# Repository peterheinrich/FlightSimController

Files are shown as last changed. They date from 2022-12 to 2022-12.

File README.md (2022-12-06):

# Overview
This small project implements a controller board intended for use in DIY flight simulator cockpits. The goal of the project is to create a versatile
hardware component suitable for a variety of simulated instruments (from buttons, dials and lights to glass cockpits), using a common bus 
interconnect and a common programming model and environment.

# Basic Requirements
- Flexible I/O (3.3 V digital I/O, high current H-bridge for stepper motors, analog input for sliders and potentiometers).
- Raspberry Pi CM4 connectors with HDMI/USB and parallel display connectors for resolutions (320x240 to 4k)
- RP2040 microcontroller for all low-spped I/O
- RS485 bus connector with integrated power supply via D-SUB-9 connector

# Current Project State
!!! EXPERIMENTAL, DESIGN ONLY !!!

Board Schematic:
[Schematic](/assets/FlightSimController-Schematics.pdf)

Rendered board view (front):
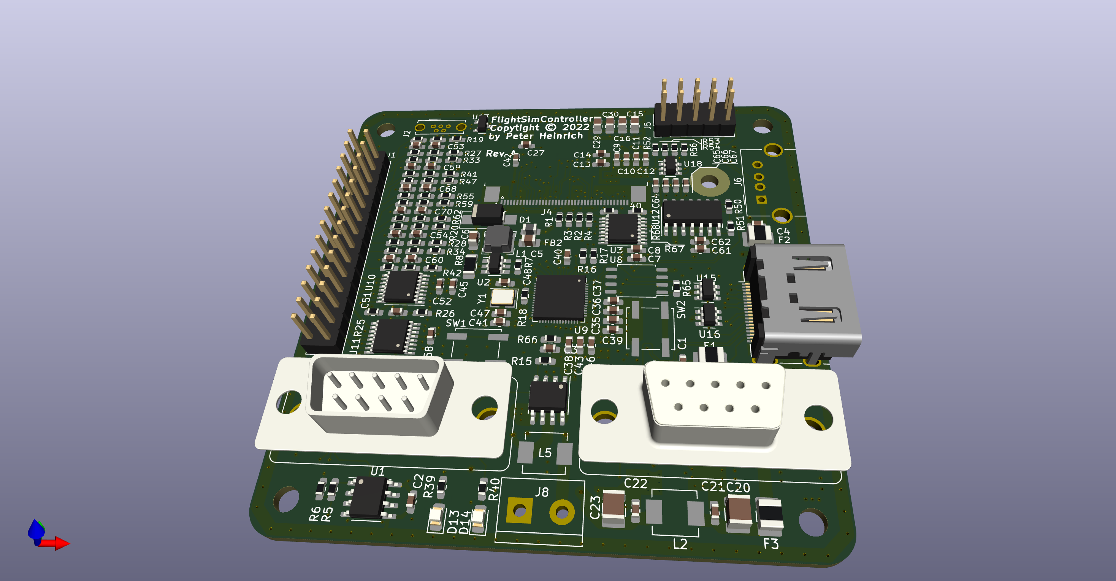
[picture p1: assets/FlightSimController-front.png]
Board-Front


Rendered board view (back):
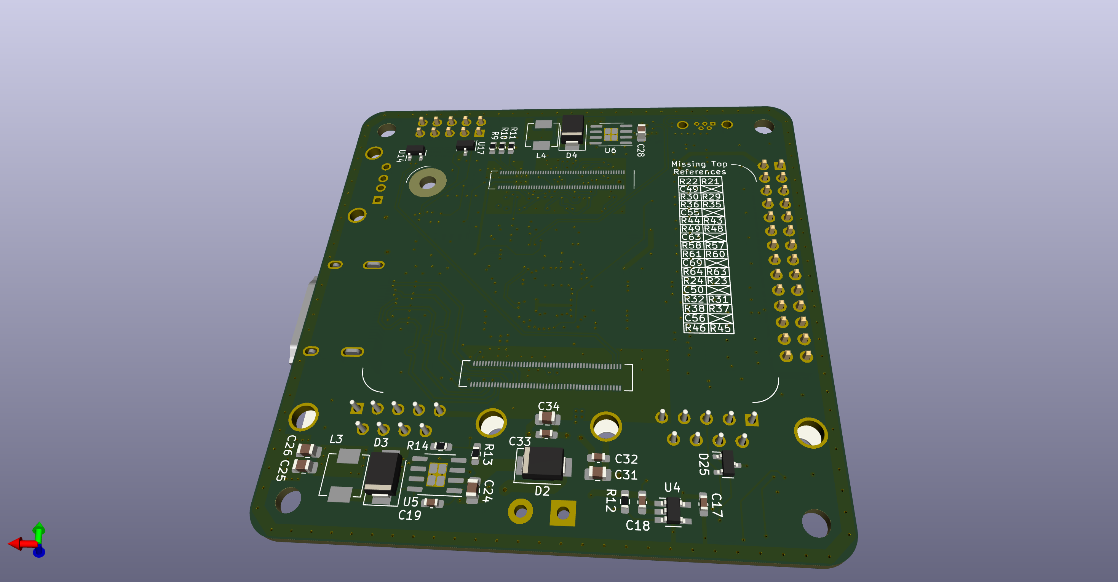
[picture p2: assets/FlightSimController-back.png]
Board-Back


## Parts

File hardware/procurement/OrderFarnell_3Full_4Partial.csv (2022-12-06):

Nr_Brd_Full | Qty_FULL | Nr_Brd_Partial | Qty_PARTIAL | QTY_TOATL | ON_FARNELL | MPN | Order_Code
3 | 35 | 4 | 27 | 213 | 1414610 | C0603C104K4RACTU | 1414610,213,C0603C104K4RACTU
3 | 6 | 4 | 3 | 30 | 9402080 | CC0603KRX5R6BB105 | 9402080,30,CC0603KRX5R6BB105
3 | 2 | 4 | 0 | 6 | 2611942 | GRM21BR61H475KE51L | 2611942,6,GRM21BR61H475KE51L
3 | 2 | 4 | 0 | 6 | 2611939 | GRM21BR61A476ME15L | 2611939,6,GRM21BR61A476ME15L
3 | 2 | 4 | 2 | 14 | 2309033 | EMK325ABJ107MM-T | 2309033,14,EMK325ABJ107MM-T
3 | 4 | 4 | 4 | 28 | 1762635 | GRM21BR61C106KE15L | 1762635,28,GRM21BR61C106KE15L
3 | 4 | 4 | 4 | 28 | 1907510 | GRM21BR61E226ME44L | 1907510,28,GRM21BR61E226ME44L
3 | 2 | 4 | 2 | 14 | 2773145 | C0603C270K5GACTU | 2773145,14,C0603C270K5GACTU
3 | 12 | 4 | 12 | 84 | 722236 | CC0603KRX7R9BB103 | 722236,84,CC0603KRX7R9BB103
3 | 1 | 4 | 0 | 3 | 9551280 | SS14-E3/61T | 9551280,3,SS14-E3/61T
3 | 3 | 4 | 3 | 21 | 1336557 | SSB44-E3/52T | 1336557,21,SSB44-E3/52T
3 | 1 | 4 | 1 | 7 | 3796308 | MP008279 | 3796308,7,MP008279
3 | 1 | 4 | 1 | 7 | 3796325 | MP008293 | 3796325,7,MP008293
3 | 1 | 4 | 1 | 7 | 2749175 | SM712-02HTG | 2749175,7,SM712-02HTG
3 | 2 | 4 | 0 | 6 | 2850019 | MCCFB1206TFF/375 | 2850019,6,MCCFB1206TFF/375
3 | 1 | 4 | 1 | 7 | 1652164 | SF-1206S300-2 | 1652164,7,SF-1206S300-2
3 | 3 | 4 | 0 | 9 | 1515661 | BLM21PG221SN1D | 1515661,9,BLM21PG221SN1D
3 | 1 | 4 | 1 | 7 | 3881938 | 68691-440HLF | 3881938,7,68691-440HLF
3 | 1 | 4 | 1 | 7 | 2470821 | 614105150721 | 2470821,7,614105150721
3 | 1 | 4 | 0 | 3 | 3465045 | 208658-1001 | 3465045,3,208658-1001
3 | 1 | 4 | 0 | 3 | 2528035 | 4-1734839-0 | 2528035,3,4-1734839-0
3 | 1 | 4 | 1 | 7 | 1248135 | 826925-5 | 1248135,7,826925-5
3 | 1 | 4 | 0 | 3 | 1450206 | 67643-0910 | 1450206,3,67643-0910
3 | 1 | 4 | 1 | 7 | 2401261 | L777TSEG09POL2RM8 | 2401261,7,L777TSEG09POL2RM8
3 | 1 | 4 | 1 | 7 | 1131855 | PM5.08/2/90 BLK | 1131855,7,PM5.08/2/90 BLK
3 | 1 | 4 | 1 | 7 | 2401266 | L77TSEH09SOL2RM8 | 2401266,7,L77TSEH09SOL2RM8
3 | 1 | 4 | 0 | 3 | 2329224 | SRN4018-330M | 2329224,3,SRN4018-330M
3 | 4 | 4 | 4 | 28 | 1698010 | IHLP2020BZER4R7M01 | 1698010,28,IHLP2020BZER4R7M01
3 | 2 | 4 | 0 | 6 | 2427678 | DF40C-100DP-0.4V(51) | 2427678,6,DF40C-100DP-0.4V(51)
3 | 9 | 4 | 2 | 35 | 9233130 | RC0603JR-070RL | 9233130,35,RC0603JR-070RL
3 | 3 | 4 | 3 | 21 | 9238549 | RC0603FR-073K3L | 9238549,21,RC0603FR-073K3L
3 | 1 | 4 | 1 | 7 | 3951237 | RC0603FR-132K2L | 3951237,7,RC0603FR-132K2L
3 | 9 | 4 | 8 | 59 | 9238603 | RC0603FR-0710KL | 9238603,59,RC0603FR-0710KL
3 | 1 | 4 | 0 | 3 | 3223654 | CR1206AF/-4R70EAS | 3223654,3,CR1206AF/-4R70EAS
3 | 1 | 4 | 1 | 7 | 3951497 | RC0603FR-071KP | 3951497,7,RC0603FR-071KP
3 | 2 | 4 | 2 | 14 | 3951609 | RC0603FR-0727R4L | 3951609,14,RC0603FR-0727R4L
3 | 2 | 4 | 2 | 14 | 9233385 | RC0603JR-071KL | 9233385,14,RC0603JR-071KL
3 | 12 | 4 | 12 | 84 | 2309107 | RC0603FR-13100KL | 2309107,84,RC0603FR-13100KL
3 | 24 | 4 | 24 | 168 | 9238425 | RC0603FR-07330RL | 9238425,168,RC0603FR-07330RL
3 | 4 | 4 | 4 | 28 | 3951355 | RC0603FR-074K7P | 3951355,28,RC0603FR-074K7P
3 | 2 | 4 | 2 | 14 | 3464290 | KSC721J LFS | 3464290,14,KSC721J LFS
3 | 1 | 4 | 1 | 7 | 2519495 | MAX485CSA+ | 2519495,7,MAX485CSA+
3 | 1 | 4 | 0 | 3 | 1824780 | TS19371CX6 RFG | 1824780,3,TS19371CX6 RFG
3 | 1 | 4 | 0 | 3 | 3008610 | TSC2007IPWR | 3008610,3,TSC2007IPWR
3 | 1 | 4 | 1 | 7 | 2849778 | LD2980ABM50TR | 2849778,7,LD2980ABM50TR
3 | 1 | 4 | 1 | 7 | 4028954 | ADP2303ARDZ-3.3-R7 | 4028954,7,ADP2303ARDZ-3.3-R7
3 | 1 | 4 | 1 | 7 | 4028955 | ADP2303ARDZ-5.0-R7 | 4028955,7,ADP2303ARDZ-5.0-R7
3 | 1 | 4 | 1 | 7 | 2807044 | VN5E160STR-E | 2807044,7,VN5E160STR-E
3 | 1 | 4 | 1 | 7 | 2901144 | IS25LP128F-JBLE | 2901144,7,IS25LP128F-JBLE
3 | 1 | 4 | 1 | 7 | 3766082 | RP2040CT | 3766082,7,RP2040CT
3 | 2 | 4 | 2 | 14 | 3869998 | TC78H611FNG(O,EL) | 3869998,14,TC78H611FNG(O,EL)
3 | 1 | 4 | 1 | 7 | 1630424 | MCP3424-E/SL | 1630424,7,MCP3424-E/SL
3 | 3 | 4 | 2 | 17 | 3116498 | TPD2E009DBZR | 3116498,17,TPD2E009DBZR
3 | 3 | 4 | 1 | 13 | 1751962 | HDMIULC6-4SC6 | 1751962,13,HDMIULC6-4SC6
3 | 1 | 4 | 1 | 7 | 2308709 | ABM8G-12.000MHZ-18-D2Y-T | 2308709,7,ABM8G-12.000MHZ-18-D2Y-T

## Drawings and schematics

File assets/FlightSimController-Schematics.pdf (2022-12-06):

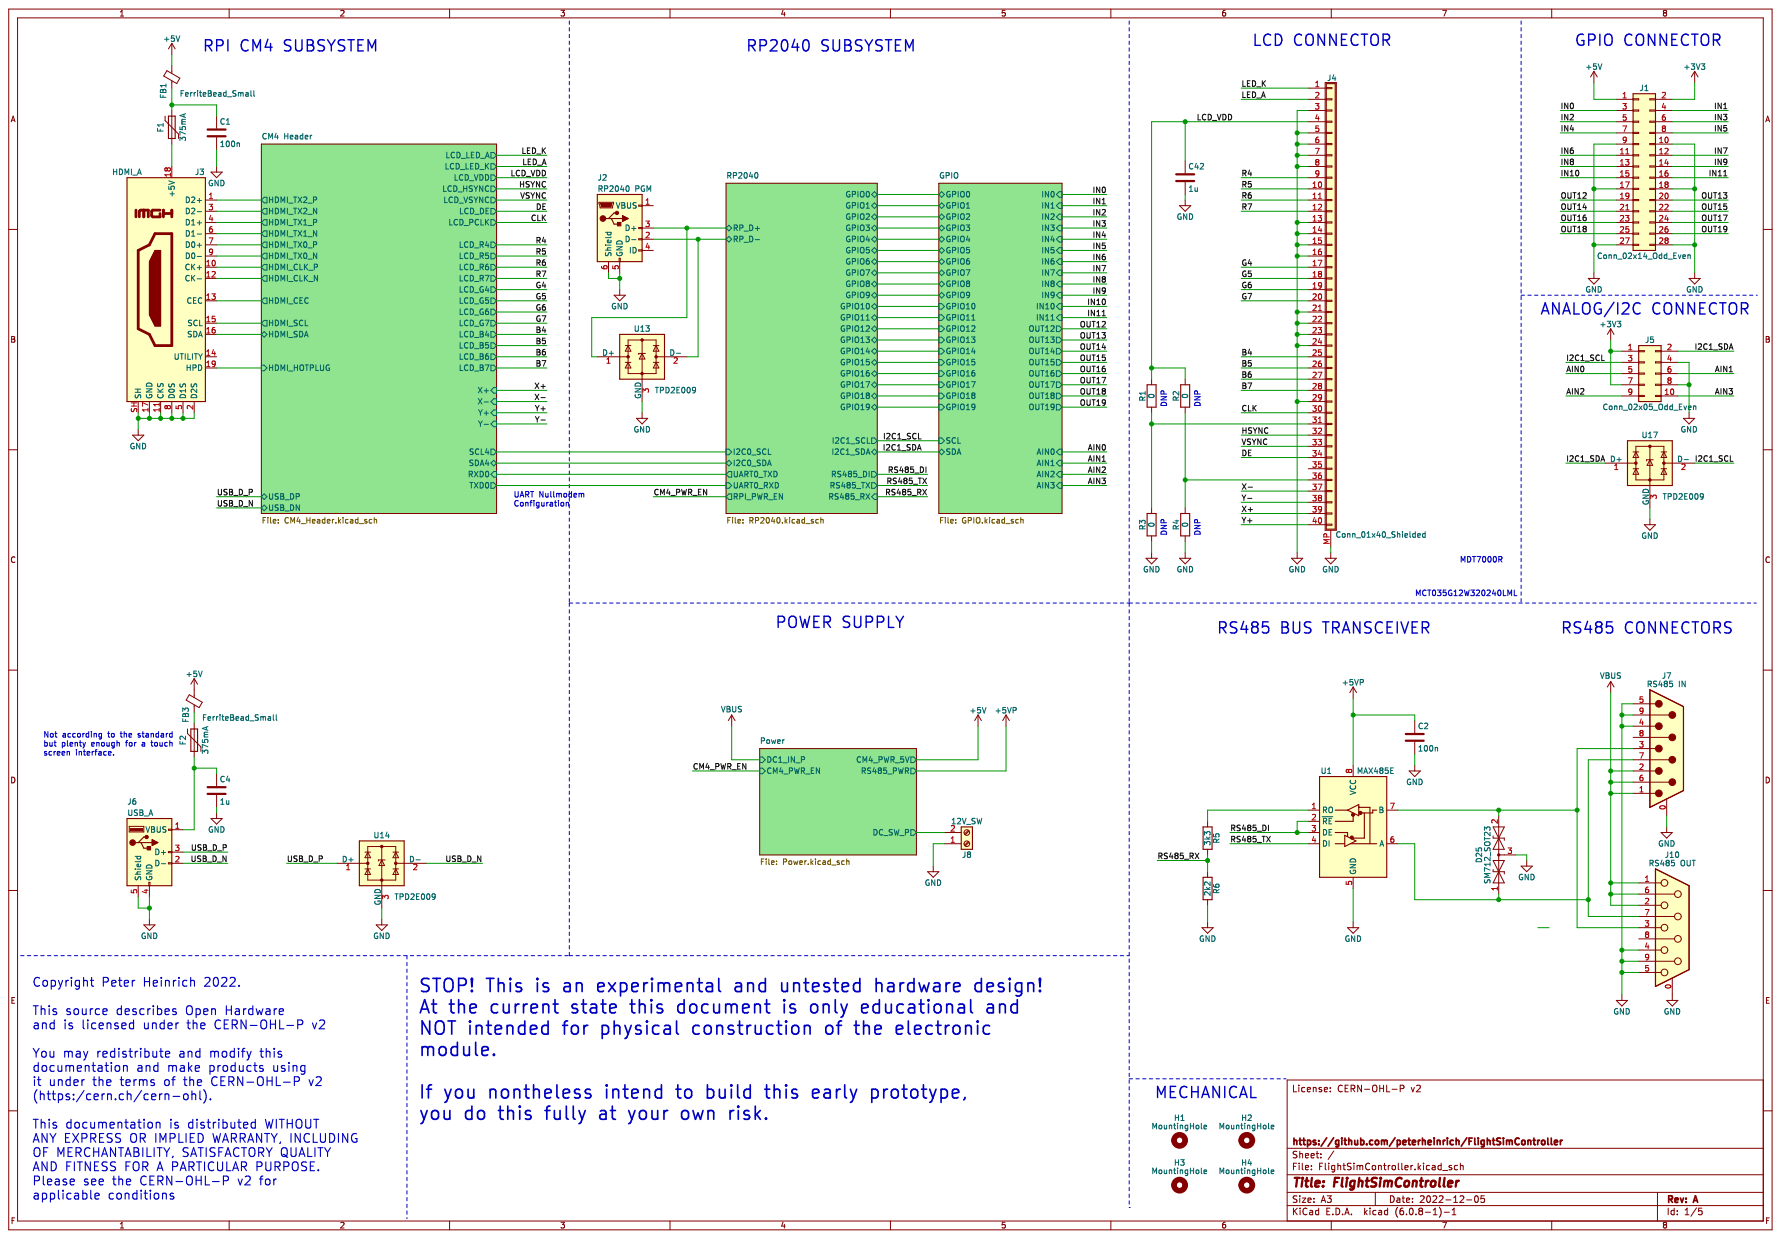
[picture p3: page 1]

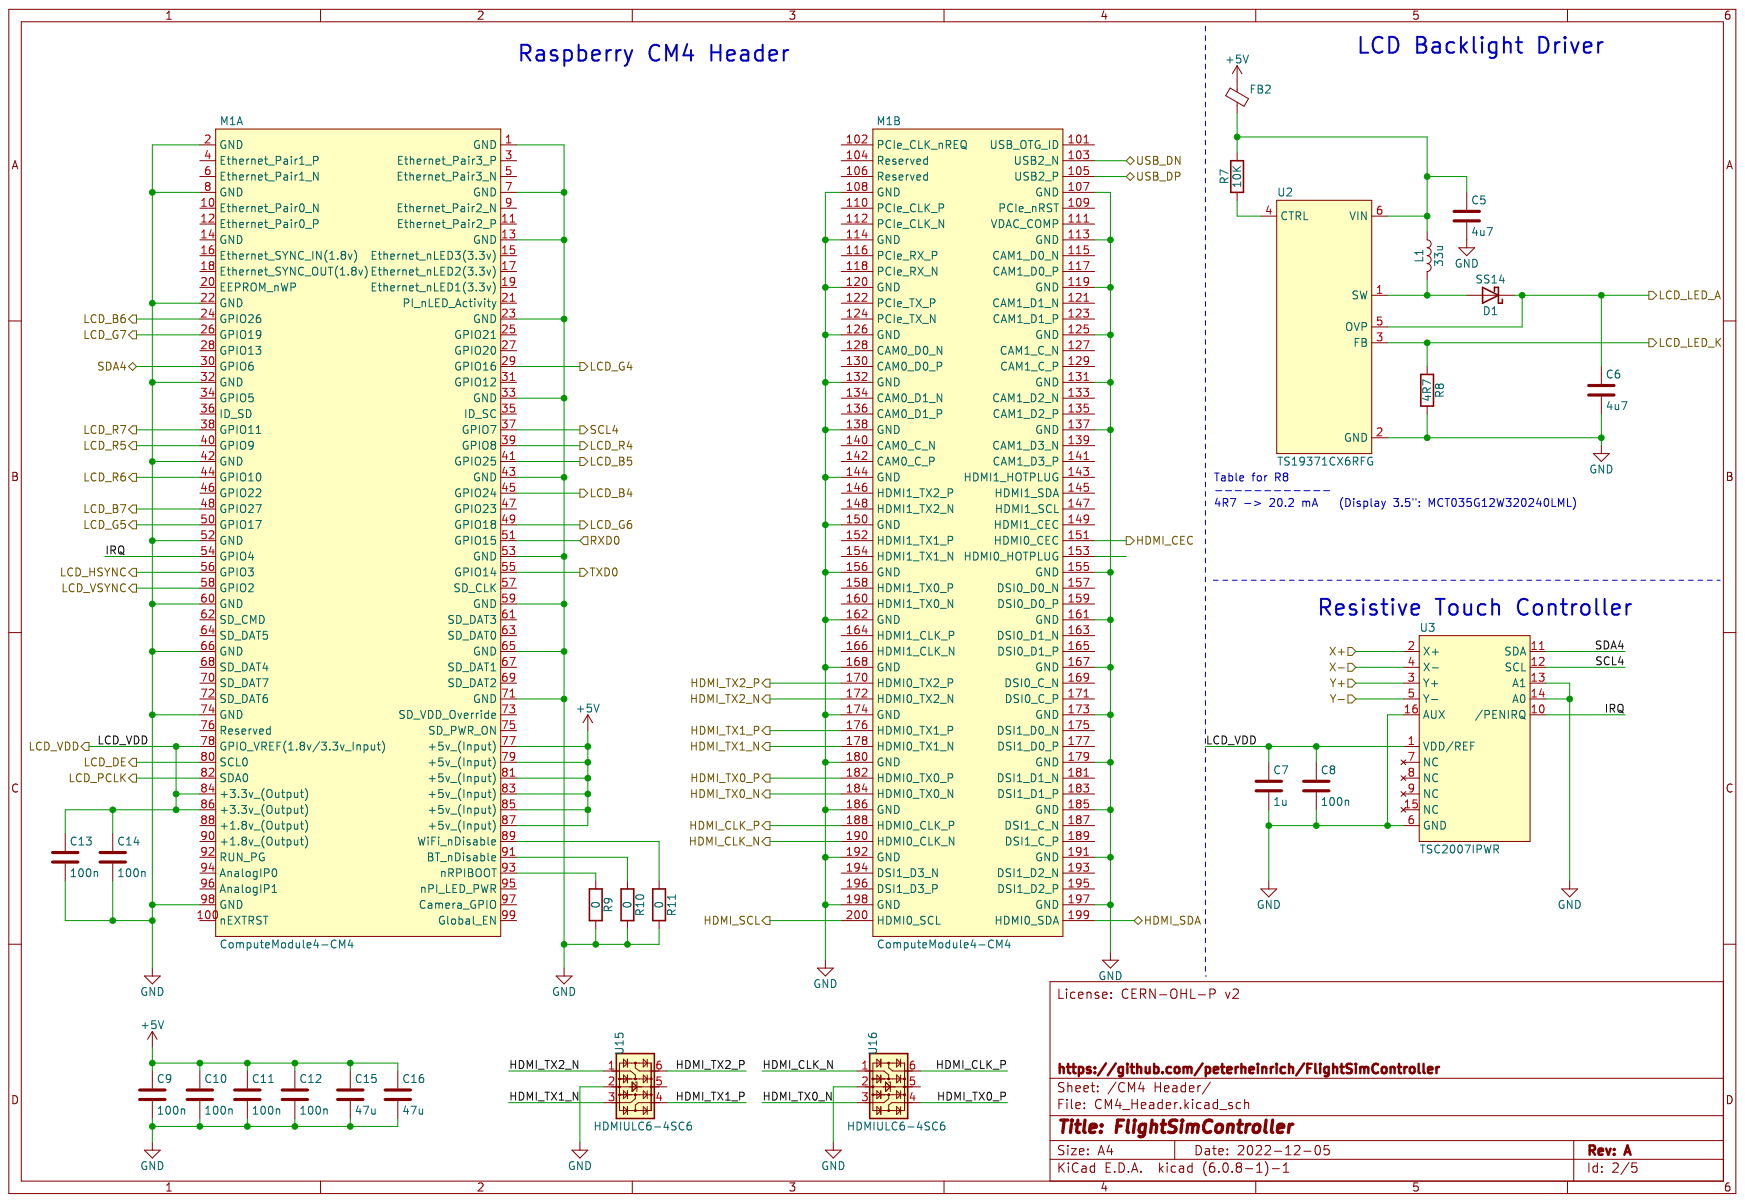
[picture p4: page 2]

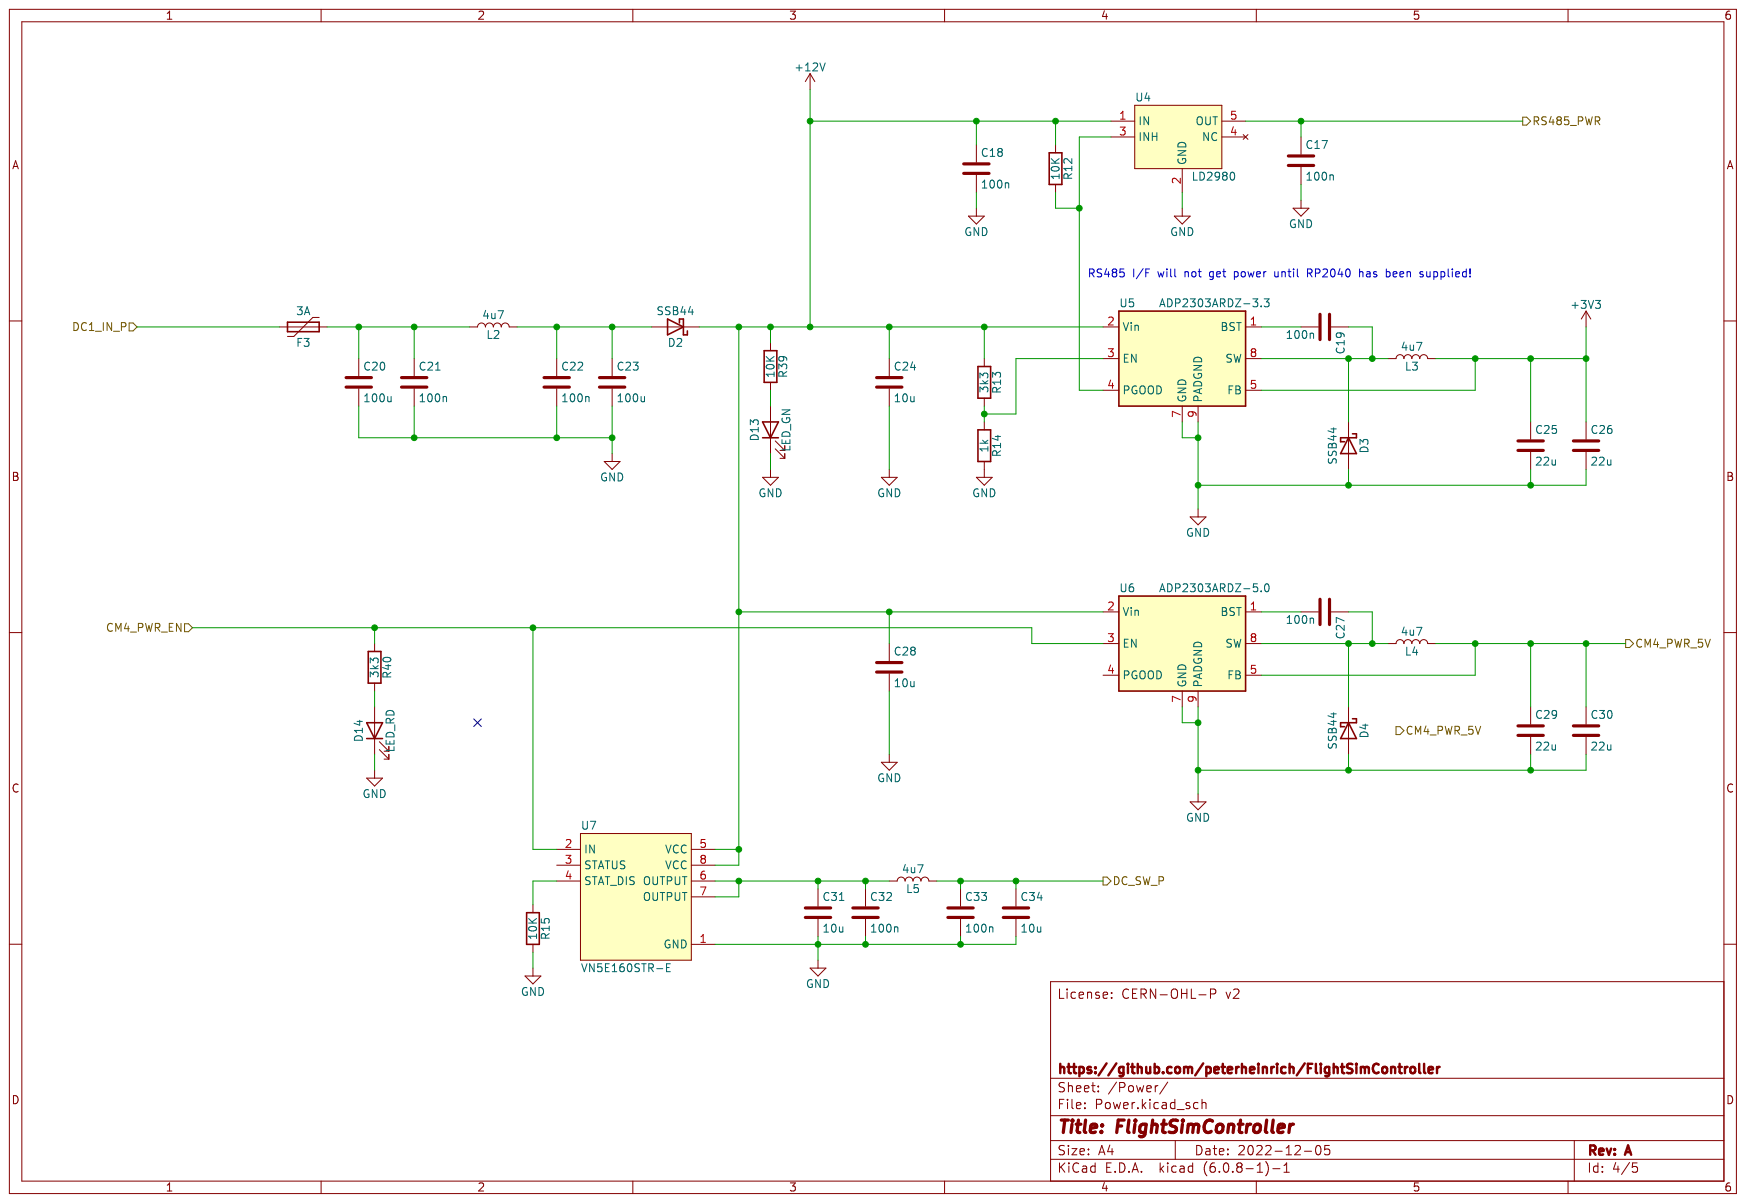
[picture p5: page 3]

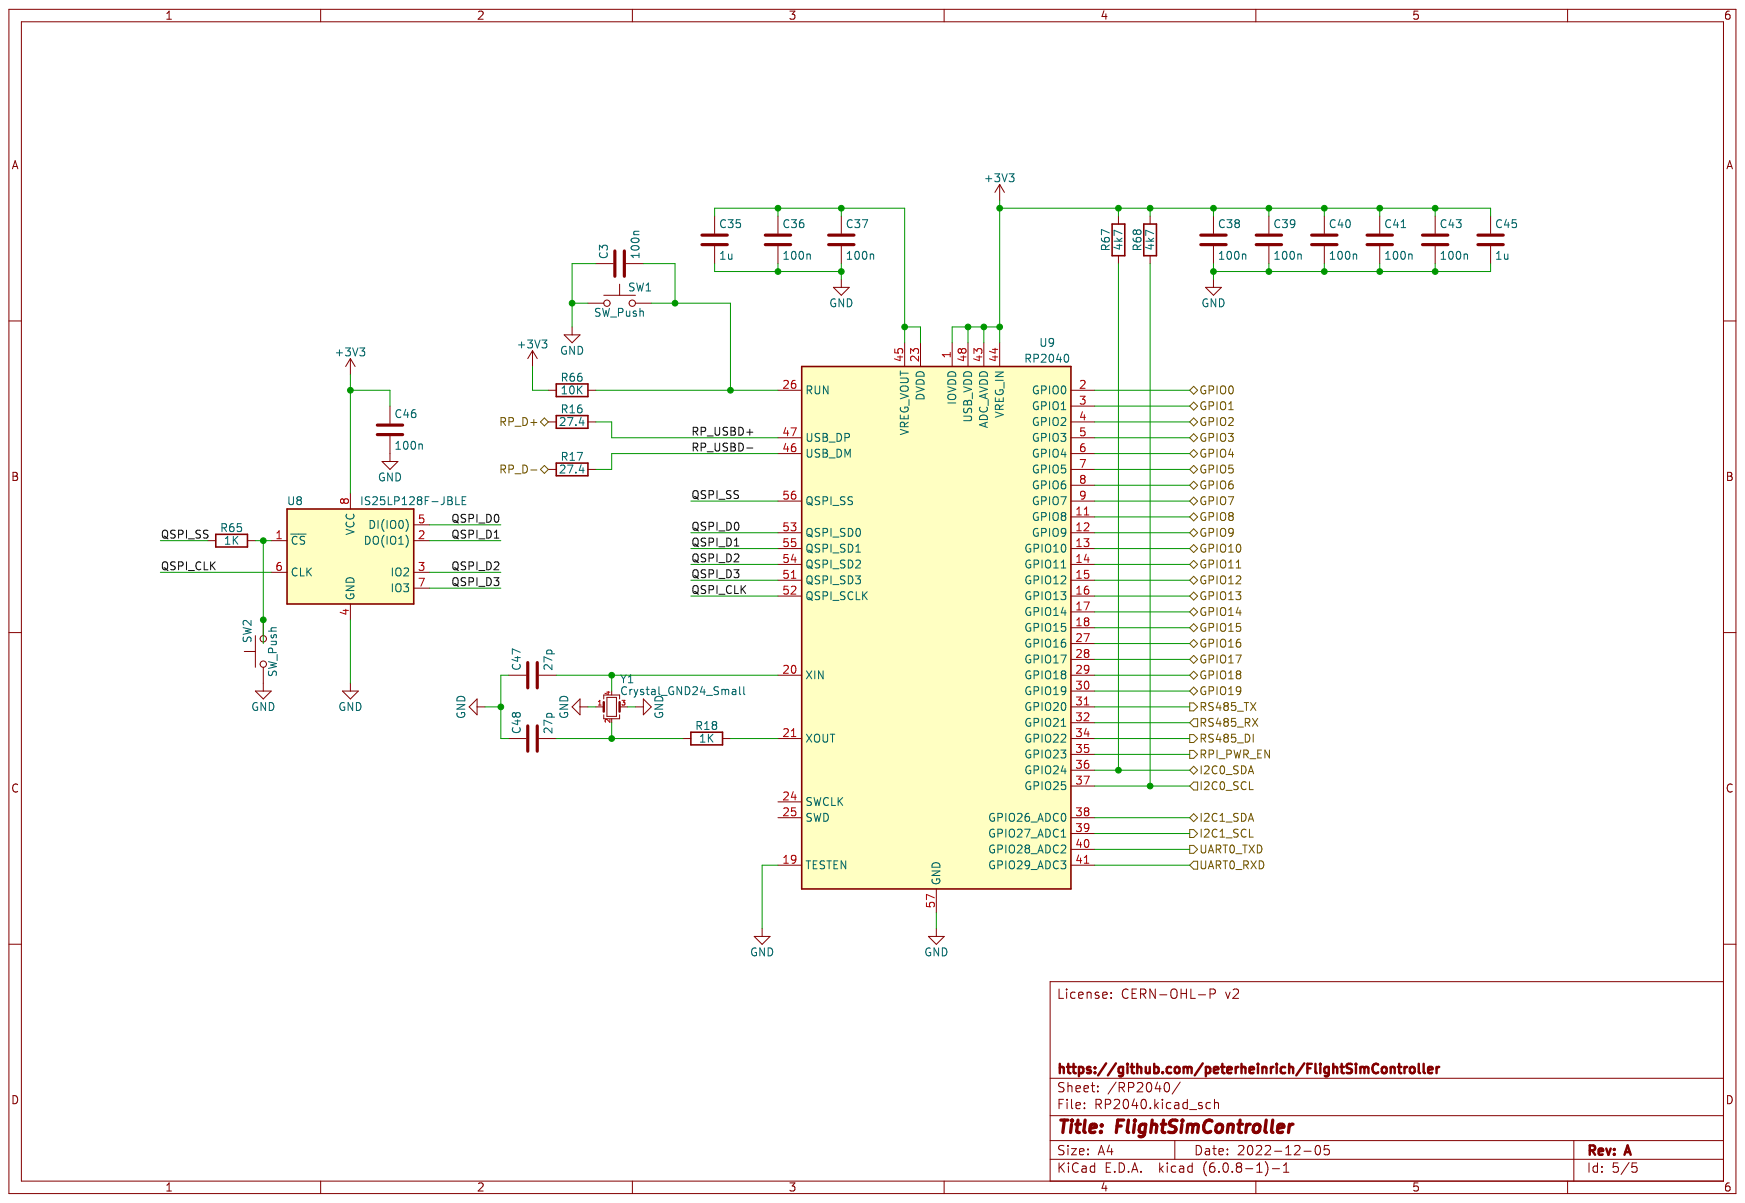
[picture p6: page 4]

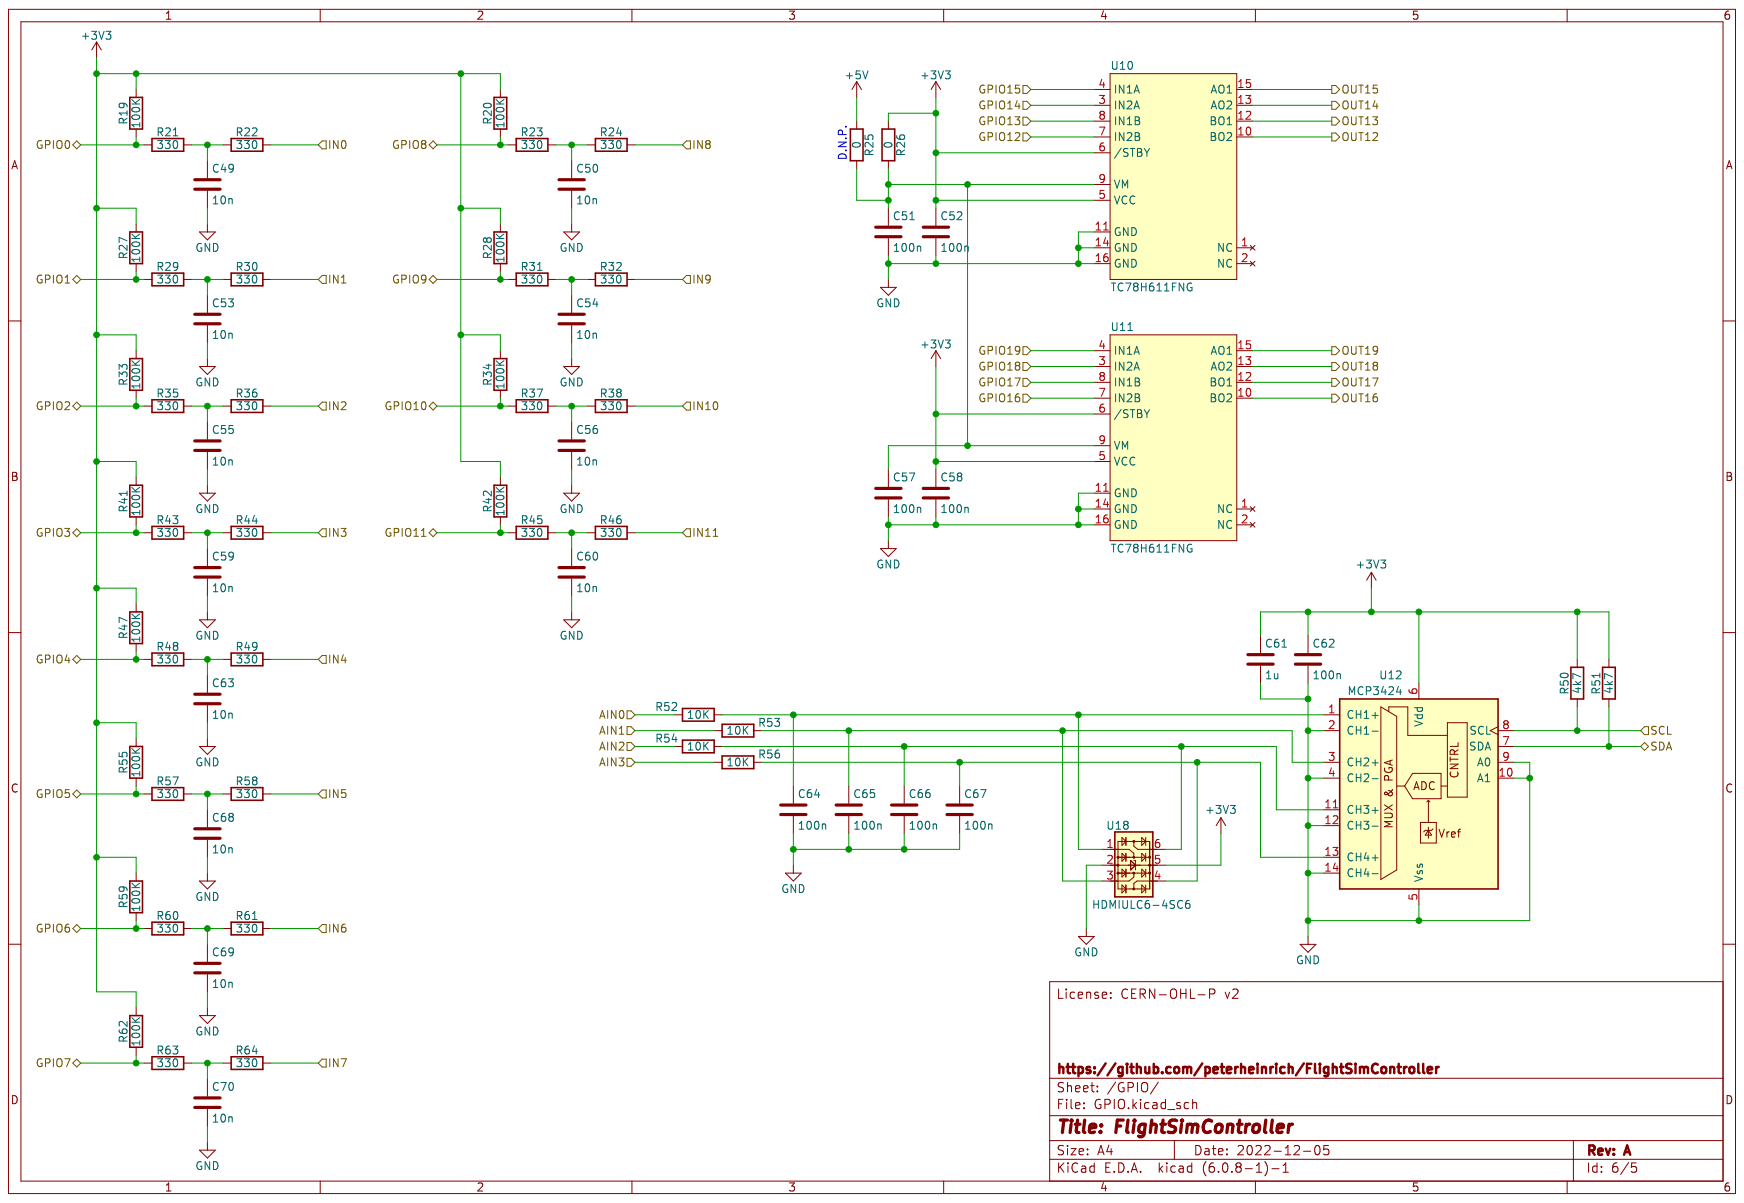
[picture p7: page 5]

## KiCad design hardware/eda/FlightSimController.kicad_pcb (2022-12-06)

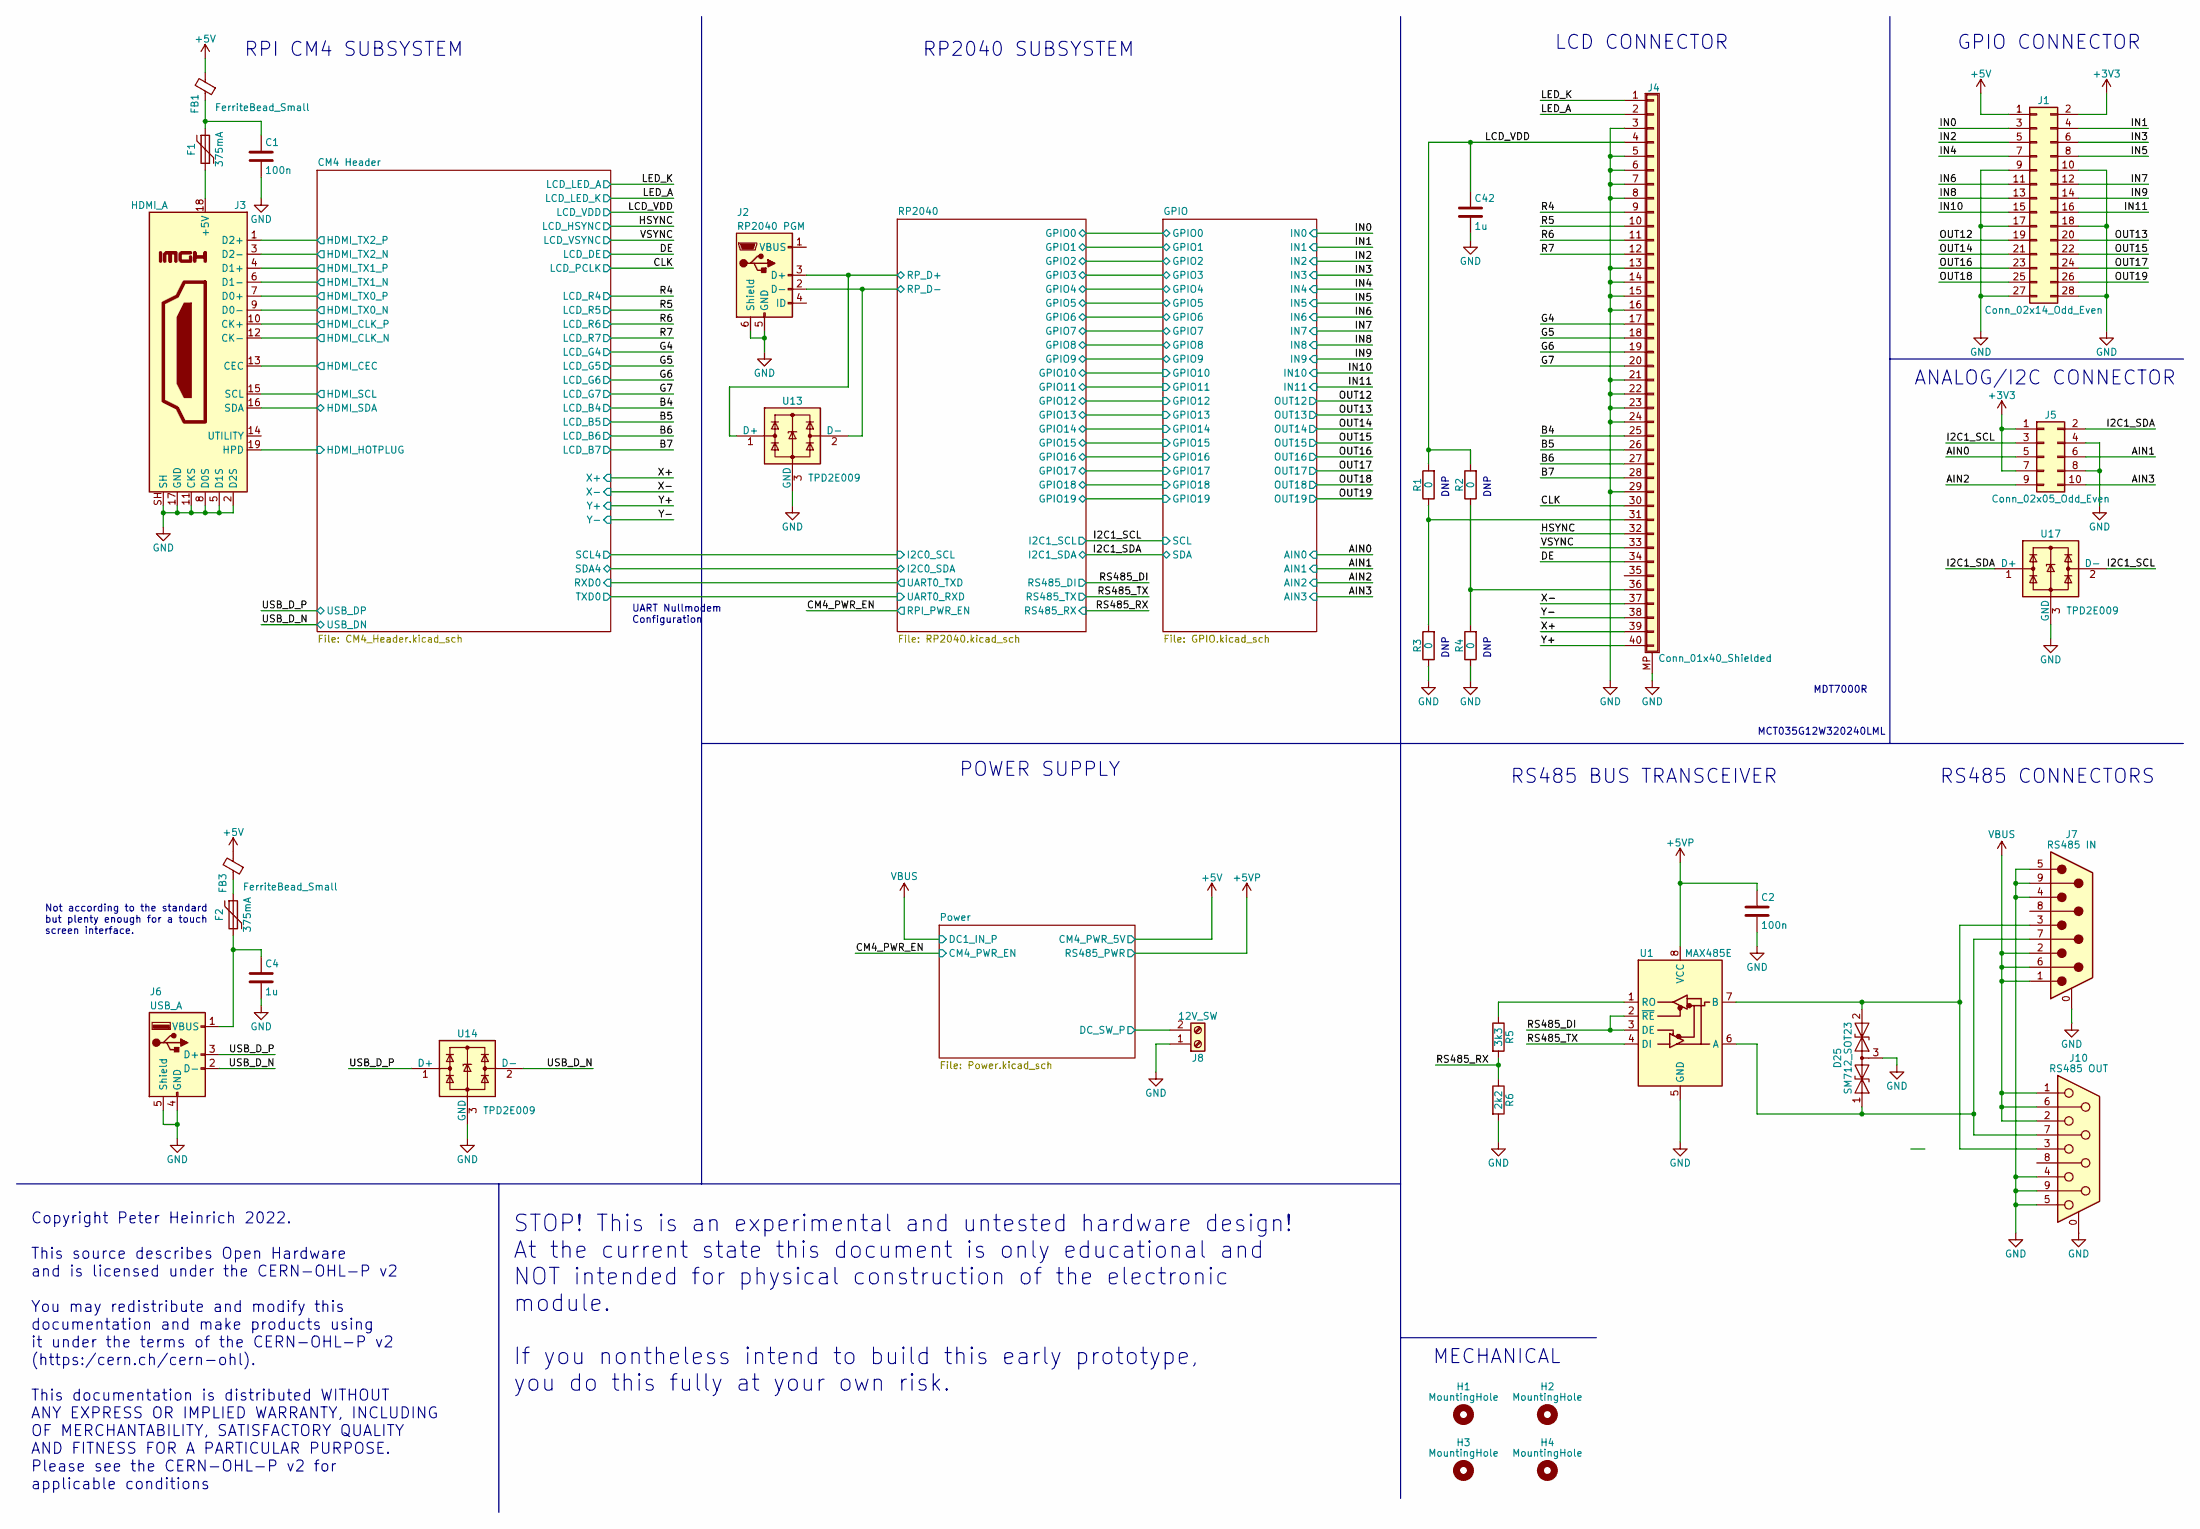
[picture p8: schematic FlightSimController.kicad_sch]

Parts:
C1, C2: 100n; C_0603_1608Metric_Pad1.08x0.95mm_HandSolder; MPN C0603C104K4RACTU
C4, C42: 1u; C_0603_1608Metric_Pad1.08x0.95mm_HandSolder; MPN CC0603KRX5R6BB105
D25: SM712_SOT23; SOT-23; MPN SM712-02HTG
F1, F2: 375mA; Fuse_1210_3225Metric_Pad1.42x2.65mm_HandSolder; MPN MCCFB1206TFF/375
FB1, FB3: FerriteBead_Small; L_0805_2012Metric; MPN BLM21PG221SN1D
H1, H2, H3, H4: MountingHole; MountingHole_3.2mm_M3_DIN965
J1: Conn_02x14_Odd_Even; PinHeader_2x14_P2.54mm_Vertical; MPN 68691-440HLF
J2: RP2040 PGM; USB_Micro-B_Wuerth_614105150721_Vertical_CircularHoles; MPN 614105150721
J3: HDMI_A; HDMI_A_Molex_208658-1001_Horizontal; MPN 208658-1001
J4: Conn_01x40_Shielded; TE_4-1734839-0_1x40-1MP_P0.5mm_Horizontal; MPN 4-1734839-0
J5: Conn_02x05_Odd_Even; PinHeader_2x05_P2.54mm_Vertical; MPN 826925-5
J6: USB_A; USB_A_Molex_67643_Horizontal; MPN 67643-0910
J7: RS485 IN; DSUB-9_Male_Vertical_P2.77x2.84mm_MountingHoles; MPN L777TSEG09POL2RM8
J8: 12V_SW; TerminalBlock_bornier-2_P5.08mm; MPN PM5.08/2/90 BLK
J10: RS485 OUT; DSUB-9_Female_Vertical_P2.77x2.84mm_MountingHoles; MPN L77TSEH09SOL2RM8
R1, R2, R3, R4: 0; R_0603_1608Metric_Pad0.98x0.95mm_HandSolder; MPN RC0603JR-070RL
R5: 3k3; R_0603_1608Metric_Pad0.98x0.95mm_HandSolder; MPN RC0603FR-073K3L
R6: 2k2; R_0603_1608Metric_Pad0.98x0.95mm_HandSolder; MPN RC0603FR-132K2L
U1: MAX485E; SOIC-8_3.9x4.9mm_P1.27mm; MPN MAX485CSA+
U13, U14, U17: TPD2E009; SOT-23; MPN TPD2E009DBZR

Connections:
+3V3: J1.2, J5.1, J5.7; also elsewhere on the board
+5V: FB1.2, FB3.2, J1.1; also elsewhere on the board
+5VP: C2.1, U1.8 (VCC); also elsewhere on the board
/AIN0: J5.5; also elsewhere on the board
/AIN1: J5.6; also elsewhere on the board
/AIN2: J5.9; also elsewhere on the board
/AIN3: J5.10; also elsewhere on the board
/B4: J4.25; also elsewhere on the board
/B5: J4.26; also elsewhere on the board
/B6: J4.27; also elsewhere on the board
/B7: J4.28; also elsewhere on the board
/CLK: J4.30; also elsewhere on the board
/CM4 Header/HDMI_CEC: J3.13 (CEC); also elsewhere on the board
/CM4 Header/HDMI_CLK_N: J3.12 (CK-); also elsewhere on the board
/CM4 Header/HDMI_CLK_P: J3.10 (CK+); also elsewhere on the board
/CM4 Header/HDMI_SCL: J3.15 (SCL); also elsewhere on the board
/CM4 Header/HDMI_SDA: J3.16 (SDA); also elsewhere on the board
/CM4 Header/HDMI_TX0_N: J3.9 (D0-); also elsewhere on the board
/CM4 Header/HDMI_TX0_P: J3.7 (D0+); also elsewhere on the board
/CM4 Header/HDMI_TX1_N: J3.6 (D1-); also elsewhere on the board
/CM4 Header/HDMI_TX1_P: J3.4 (D1+); also elsewhere on the board
/CM4 Header/HDMI_TX2_N: J3.3 (D2-); also elsewhere on the board
/CM4 Header/HDMI_TX2_P: J3.1 (D2+); also elsewhere on the board
/DE: J4.34; also elsewhere on the board
/G4: J4.17; also elsewhere on the board
/G5: J4.18; also elsewhere on the board
/G6: J4.19; also elsewhere on the board
/G7: J4.20; also elsewhere on the board
/HDMI_HOTPLUG: J3.19 (HPD)
/HSYNC: J4.32; also elsewhere on the board
/I2C1_SCL: J5.3, U17.2 (D-); also elsewhere on the board
/I2C1_SDA: J5.2, U17.1 (D+); also elsewhere on the board
/IN0: J1.3; also elsewhere on the board
/IN1: J1.4; also elsewhere on the board
/IN2: J1.5; also elsewhere on the board
/IN3: J1.6; also elsewhere on the board
/IN4: J1.7; also elsewhere on the board
/IN5: J1.8; also elsewhere on the board
/IN6: J1.11; also elsewhere on the board
/IN7: J1.12; also elsewhere on the board
/IN8: J1.13; also elsewhere on the board
/IN9: J1.14; also elsewhere on the board
/IN10: J1.15; also elsewhere on the board
/IN11: J1.16; also elsewhere on the board
/LCD_VDD: C42.1, J4.4, R1.2, R2.2; also elsewhere on the board
/LED_A: J4.2; also elsewhere on the board
/LED_K: J4.1; also elsewhere on the board
/OUT12: J1.19; also elsewhere on the board
/OUT13: J1.20; also elsewhere on the board
/OUT14: J1.21; also elsewhere on the board
/OUT15: J1.22; also elsewhere on the board
/OUT16: J1.23; also elsewhere on the board
/OUT17: J1.24; also elsewhere on the board
/OUT18: J1.25; also elsewhere on the board
/OUT19: J1.26; also elsewhere on the board
/Power/DC_SW_P: J8.2; also elsewhere on the board
/R4: J4.9; also elsewhere on the board
/R5: J4.10; also elsewhere on the board
/R6: J4.11; also elsewhere on the board
/R7: J4.12; also elsewhere on the board
/RP2040/RP_D+: J2.3 (D+), U13.1 (D+); also elsewhere on the board
/RP2040/RP_D-: J2.2 (D-), U13.2 (D-); also elsewhere on the board
/RS485_DI: U1.2 (~RE), U1.3 (DE); also elsewhere on the board
/RS485_RX: R5.2, R6.1; also elsewhere on the board
/RS485_TX: U1.4 (DI); also elsewhere on the board
/USB_D_N: J6.2 (D-), U14.2 (D-); also elsewhere on the board
/USB_D_P: J6.3 (D+), U14.1 (D+); also elsewhere on the board
/VSYNC: J4.33; also elsewhere on the board
/X+: J4.39; also elsewhere on the board
/X-: J4.37; also elsewhere on the board
/Y+: J4.40; also elsewhere on the board
/Y-: J4.38; also elsewhere on the board
GND: C1.2, C2.2, C4.2, C42.2, D25.3 (common), J1.9, J1.10, J1.17, J1.18, J1.27, J1.28, J2.5 (GND), J2.6 (Shield), J3.2 (D2S), J3.5 (D1S), J3.8 (D0S), J3.11 (CKS), J3.17 (GND), J3.SH, J4.3, J4.5, J4.6, J4.7, J4.8, J4.13, J4.14, J4.15, J4.16, J4.21, J4.22, J4.23, J4.24, J4.29, J4.MP (Shield), J5.4, J5.8, J6.4 (GND), J6.5 (Shield), J7.0 (PAD), J7.4, J7.5, J7.9, J8.1, J10.0 (PAD), J10.4, J10.5, J10.9, R3.1, R4.1, R6.2, U1.5 (GND), U13.3 (GND), U14.3 (GND), U17.3 (GND); also elsewhere on the board
unnamed: C1.1, F1.1, FB1.1
unnamed: C4.1, F2.2, J6.1 (VBUS)
unnamed: D25.1 (A1), J7.7, J10.7, U1.6 (A)
unnamed: D25.2 (A2), J7.3, J10.3, U1.7 (B)
unnamed: F1.2, J3.18 (+5V)
unnamed: F2.1, FB3.1
unnamed: J4.31, R1.1, R3.2
unnamed: J4.36, R2.1, R4.2
unnamed: R5.1, U1.1 (RO)
VBUS: J7.1, J7.2, J7.6, J10.1, J10.2, J10.6; also elsewhere on the board

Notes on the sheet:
UART Nullmodem Configuration
DNP
RPI CM4 SUBSYSTEM
MCT035G12W320240LML
LCD CONNECTOR
GPIO CONNECTOR
POWER SUPPLY
Not according to the standard but plenty enough for a touch screen interface.
Copyright Peter Heinrich 2022. This source describes Open Hardware and is licensed under the CERN-OHL-P v2 You may redistribute and modify this documentation and make products using it under the terms of the CERN-OHL-P v2 (https:/cern.ch/cern-ohl). This documentation is distributed WITHOUT ANY EXPR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
RS485 CONNECTORS
MDT7000R
MECHANICAL
ANALOG/I2C CONNECTOR
RS485 BUS TRANSCEIVER
RP2040 SUBSYSTEM
STOP! This is an experimental and untested hardware design! At the current state this document is only educational and NOT intended for physical construction of the electronic module. If you nontheless intend to build this early prototype, you do this fully at your own risk.

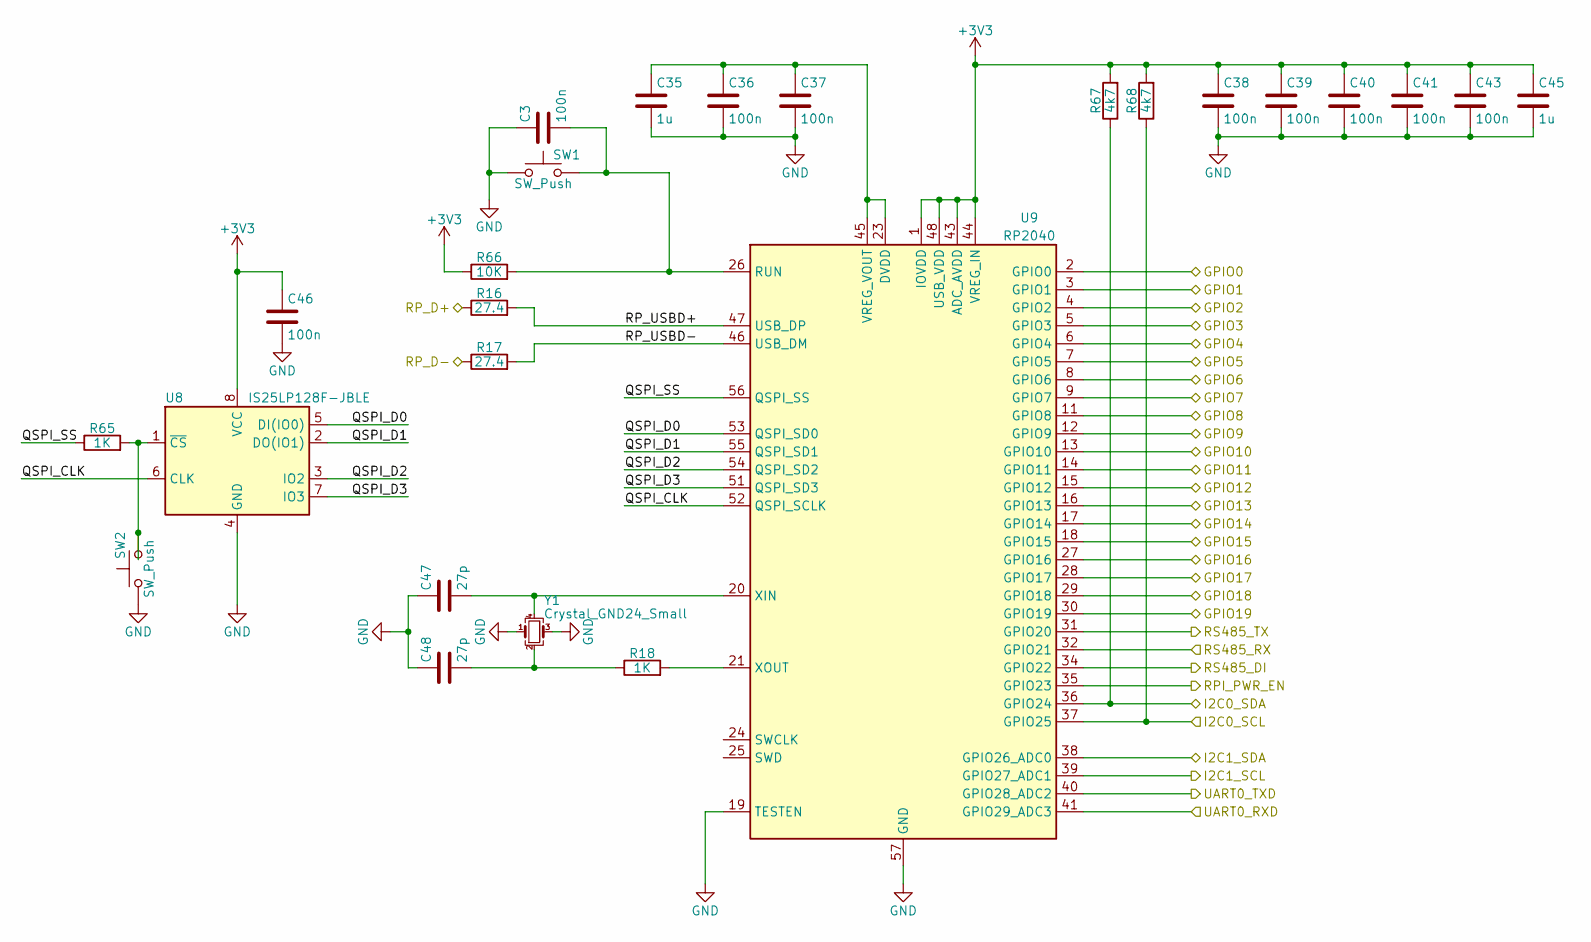
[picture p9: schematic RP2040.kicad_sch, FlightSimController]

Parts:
C3, C36, C37, C38, C39, C40, C41, C43, C46: 100n; C_0603_1608Metric_Pad1.08x0.95mm_HandSolder; MPN C0603C104K4RACTU
C35, C45: 1u; C_0603_1608Metric_Pad1.08x0.95mm_HandSolder; MPN CC0603KRX5R6BB105
C47, C48: 27p; C_0603_1608Metric_Pad1.08x0.95mm_HandSolder; MPN C0603C270K5GACTU
R16, R17: 27.4; R_0603_1608Metric_Pad0.98x0.95mm_HandSolder; MPN RC0603FR-0727R4L
R18, R65: 1K; R_0603_1608Metric_Pad0.98x0.95mm_HandSolder; MPN RC0603JR-071KL
R66: 10K; R_0603_1608Metric_Pad0.98x0.95mm_HandSolder; MPN RC0603FR-0710KL
R67, R68: 4k7; R_0603_1608Metric_Pad0.98x0.95mm_HandSolder; MPN RC0603FR-074K7L.
SW1, SW2: SW_Push; SW_Push_1P1T_NO_CK_KSC7xxJ; MPN KSC721J LFS
U8: IS25LP128F-JBLE; SOIC-8_5.23x5.23mm_P1.27mm; MPN IS25LP128F-JBLE
U9: RP2040; QFN-56-1EP_7x7mm_P0.4mm_EP3.2x3.2mm; MPN RP2040CT
Y1: Crystal_GND24_Small; Crystal_SMD_Abracon_ABM8G-4Pin_3.2x2.5mm; MPN ABM8G-12.000MHZ-18-D2Y-T

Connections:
+3V3: C38.1, C39.1, C40.1, C41.1, C43.1, C45.1, C46.1, R66.1, R67.2, R68.2, U8.8 (VCC), U9.1 (IOVDD), U9.10 (IOVDD), U9.22 (IOVDD), U9.33 (IOVDD), U9.42 (IOVDD), U9.43 (ADC_AVDD), U9.44 (VREG_IN), U9.48 (USB_VDD), U9.49 (IOVDD); also elsewhere on the board
/CM4 Header/RXD0: U9.40 (GPIO28_ADC2); also elsewhere on the board
/CM4 Header/SCL4: R68.1, U9.37 (GPIO25); also elsewhere on the board
/CM4 Header/SDA4: R67.1, U9.36 (GPIO24); also elsewhere on the board
/CM4 Header/TXD0: U9.41 (GPIO29_ADC3); also elsewhere on the board
/CM4_PWR_EN: U9.35 (GPIO23); also elsewhere on the board
/GPIO/GPIO0: U9.2 (GPIO0); also elsewhere on the board
/GPIO/GPIO1: U9.3 (GPIO1); also elsewhere on the board
/GPIO/GPIO2: U9.4 (GPIO2); also elsewhere on the board
/GPIO/GPIO3: U9.5 (GPIO3); also elsewhere on the board
/GPIO/GPIO4: U9.6 (GPIO4); also elsewhere on the board
/GPIO/GPIO5: U9.7 (GPIO5); also elsewhere on the board
/GPIO/GPIO6: U9.8 (GPIO6); also elsewhere on the board
/GPIO/GPIO7: U9.9 (GPIO7); also elsewhere on the board
/GPIO/GPIO8: U9.11 (GPIO8); also elsewhere on the board
/GPIO/GPIO9: U9.12 (GPIO9); also elsewhere on the board
/GPIO/GPIO10: U9.13 (GPIO10); also elsewhere on the board
/GPIO/GPIO11: U9.14 (GPIO11); also elsewhere on the board
/GPIO/GPIO12: U9.15 (GPIO12); also elsewhere on the board
/GPIO/GPIO13: U9.16 (GPIO13); also elsewhere on the board
/GPIO/GPIO14: U9.17 (GPIO14); also elsewhere on the board
/GPIO/GPIO15: U9.18 (GPIO15); also elsewhere on the board
/GPIO/GPIO16: U9.27 (GPIO16); also elsewhere on the board
/GPIO/GPIO17: U9.28 (GPIO17); also elsewhere on the board
/GPIO/GPIO18: U9.29 (GPIO18); also elsewhere on the board
/GPIO/GPIO19: U9.30 (GPIO19); also elsewhere on the board
/I2C1_SCL: U9.39 (GPIO27_ADC1); also elsewhere on the board
/I2C1_SDA: U9.38 (GPIO26_ADC0); also elsewhere on the board
/RP2040/QSPI_CLK: U8.6 (CLK), U9.52 (QSPI_SCLK)
/RP2040/QSPI_D0: U8.5 (DI(IO0)), U9.53 (QSPI_SD0)
/RP2040/QSPI_D1: U8.2 (DO(IO1)), U9.55 (QSPI_SD1)
/RP2040/QSPI_D2: U8.3 (IO2), U9.54 (QSPI_SD2)
/RP2040/QSPI_D3: U8.7 (IO3), U9.51 (QSPI_SD3)
/RP2040/QSPI_SS: R65.1, U9.56 (QSPI_SS)
/RP2040/RP_D+: R16.1; also elsewhere on the board
/RP2040/RP_D-: R17.1; also elsewhere on the board
/RP2040/RP_USBD+: R16.2, U9.47 (USB_DP)
/RP2040/RP_USBD-: R17.2, U9.46 (USB_DM)
/RS485_DI: U9.34 (GPIO22); also elsewhere on the board
/RS485_RX: U9.32 (GPIO21); also elsewhere on the board
/RS485_TX: U9.31 (GPIO20); also elsewhere on the board
GND: C3.1, C35.2, C36.2, C37.2, C38.2, C39.2, C40.2, C41.2, C43.2, C45.2, C46.2, C47.1, C48.1, SW1.1, SW2.1, U8.4 (GND), U9.19 (TESTEN), U9.57 (GND), Y1.1, Y1.3; also elsewhere on the board
unnamed: C3.2, R66.2, SW1.2, U9.26 (RUN)
unnamed: C35.1, C36.1, C37.1, U9.23 (DVDD), U9.45 (VREG_VOUT), U9.50 (DVDD)
unnamed: C47.2, U9.20 (XIN), Y1.4
unnamed: C48.2, R18.1, Y1.2
unnamed: R18.2, U9.21 (XOUT)
unnamed: R65.2, SW2.2, U8.1 (~CS)

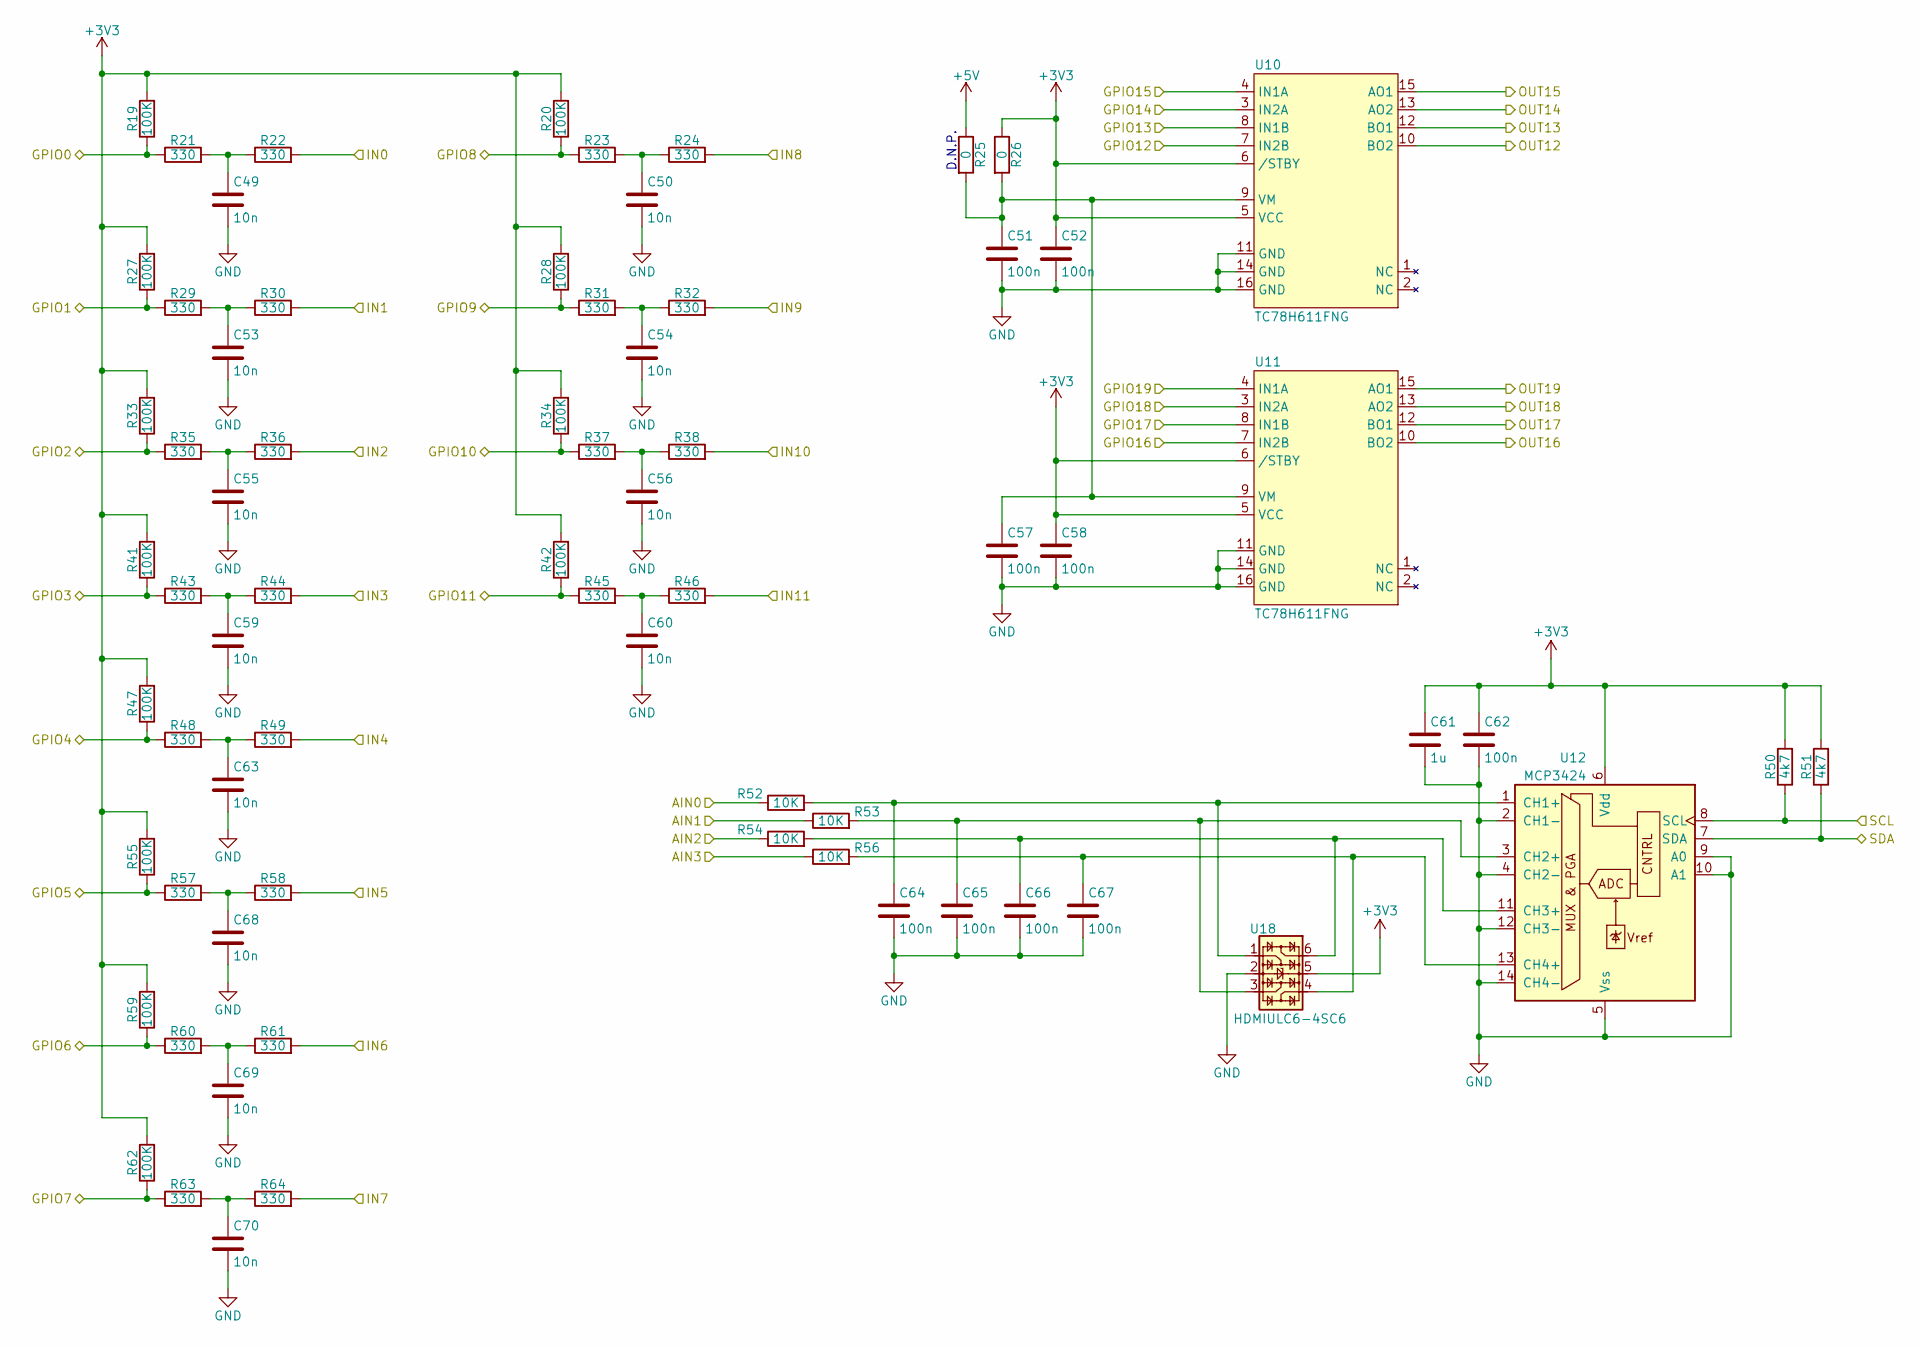
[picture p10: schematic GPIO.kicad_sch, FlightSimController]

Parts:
C49, C50, C53, C54, C55, C56, C59, C60, C63, C68, C69, C70: 10n; C_0603_1608Metric_Pad1.08x0.95mm_HandSolder; MPN CC0603KRX7R9BB103
C51, C52, C57, C58, C62, C64, C65, C66, C67: 100n; C_0603_1608Metric_Pad1.08x0.95mm_HandSolder; MPN C0603C104K4RACTU
C61: 1u; C_0603_1608Metric_Pad1.08x0.95mm_HandSolder; MPN CC0603KRX5R6BB105
R19, R20, R27, R28, R33, R34, R41, R42, R47, R55, R59, R62: 100K; R_0603_1608Metric_Pad0.98x0.95mm_HandSolder; MPN RC0603FR-13100KL
R21, R22, R23, R24, R29, R30, R31, R32, R35, R36, R37, R38, R43, R44, R45, R46, R48, R49, R57, R58, R60, R61, R63, R64: 330; R_0603_1608Metric_Pad0.98x0.95mm_HandSolder; MPN RC0603FR-07330RL
R25, R26: 0; R_0603_1608Metric_Pad0.98x0.95mm_HandSolder; MPN RC0603JR-070RL
R50, R51: 4k7; R_0603_1608Metric_Pad0.98x0.95mm_HandSolder; MPN RC0603FR-074K7L.
R52, R53, R54, R56: 10K; R_0603_1608Metric_Pad0.98x0.95mm_HandSolder; MPN RC0603FR-0710KL
U10, U11: TC78H611FNG; TSSOP-16_4.4x5mm_P0.65mm; MPN TC78H611FNG(O,EL)
U12: MCP3424; SOIC-14_3.9x8.7mm_P1.27mm; MPN MCP3424-E/SL
U18: HDMIULC6-4SC6; SOT-23-6; MPN HDMIULC6-4SC6

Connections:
+3V3: C52.1, C58.1, C61.1, C62.1, R19.2, R20.2, R26.1, R27.2, R28.2, R33.2, R34.2, R41.2, R42.2, R47.2, R50.2, R51.2, R55.2, R59.2, R62.2, U10.5 (VCC), U10.6 (/STBY), U11.5 (VCC), U11.6 (/STBY), U12.6 (Vdd), U18.5; also elsewhere on the board
+5V: R25.1; also elsewhere on the board
/AIN0: R52.1; also elsewhere on the board
/AIN1: R53.1; also elsewhere on the board
/AIN2: R54.1; also elsewhere on the board
/AIN3: R56.1; also elsewhere on the board
/GPIO/GPIO0: R19.1, R21.1; also elsewhere on the board
/GPIO/GPIO1: R27.1, R29.1; also elsewhere on the board
/GPIO/GPIO2: R33.1, R35.1; also elsewhere on the board
/GPIO/GPIO3: R41.1, R43.1; also elsewhere on the board
/GPIO/GPIO4: R47.1, R48.1; also elsewhere on the board
/GPIO/GPIO5: R55.1, R57.1; also elsewhere on the board
/GPIO/GPIO6: R59.1, R60.1; also elsewhere on the board
/GPIO/GPIO7: R62.1, R63.1; also elsewhere on the board
/GPIO/GPIO8: R20.1, R23.1; also elsewhere on the board
/GPIO/GPIO9: R28.1, R31.1; also elsewhere on the board
/GPIO/GPIO10: R34.1, R37.1; also elsewhere on the board
/GPIO/GPIO11: R42.1, R45.1; also elsewhere on the board
/GPIO/GPIO12: U10.7 (IN2B); also elsewhere on the board
/GPIO/GPIO13: U10.8 (IN1B); also elsewhere on the board
/GPIO/GPIO14: U10.3 (IN2A); also elsewhere on the board
/GPIO/GPIO15: U10.4 (IN1A); also elsewhere on the board
/GPIO/GPIO16: U11.7 (IN2B); also elsewhere on the board
/GPIO/GPIO17: U11.8 (IN1B); also elsewhere on the board
/GPIO/GPIO18: U11.3 (IN2A); also elsewhere on the board
/GPIO/GPIO19: U11.4 (IN1A); also elsewhere on the board
/I2C1_SCL: R50.1, U12.8 (SCL); also elsewhere on the board
/I2C1_SDA: R51.1, U12.7 (SDA); also elsewhere on the board
/IN0: R22.2; also elsewhere on the board
/IN1: R30.2; also elsewhere on the board
/IN2: R36.2; also elsewhere on the board
/IN3: R44.2; also elsewhere on the board
/IN4: R49.2; also elsewhere on the board
/IN5: R58.2; also elsewhere on the board
/IN6: R61.2; also elsewhere on the board
/IN7: R64.2; also elsewhere on the board
/IN8: R24.2; also elsewhere on the board
/IN9: R32.2; also elsewhere on the board
/IN10: R38.2; also elsewhere on the board
/IN11: R46.2; also elsewhere on the board
/OUT12: U10.10 (BO2); also elsewhere on the board
/OUT13: U10.12 (BO1); also elsewhere on the board
/OUT14: U10.13 (AO2); also elsewhere on the board
/OUT15: U10.15 (AO1); also elsewhere on the board
/OUT16: U11.10 (BO2); also elsewhere on the board
/OUT17: U11.12 (BO1); also elsewhere on the board
/OUT18: U11.13 (AO2); also elsewhere on the board
/OUT19: U11.15 (AO1); also elsewhere on the board
GND: C49.2, C50.2, C51.2, C52.2, C53.2, C54.2, C55.2, C56.2, C57.2, C58.2, C59.2, C60.2, C61.2, C62.2, C63.2, C64.2, C65.2, C66.2, C67.2, C68.2, C69.2, C70.2, U10.11 (GND), U10.14 (GND), U10.16 (GND), U11.11 (GND), U11.14 (GND), U11.16 (GND), U12.2 (CH1-), U12.4 (CH2-), U12.5 (Vss), U12.9 (A0), U12.10 (A1), U12.12 (CH3-), U12.14 (CH4-), U18.2; also elsewhere on the board
unnamed: C49.1, R21.2, R22.1
unnamed: C50.1, R23.2, R24.1
unnamed: C51.1, C57.1, R25.2, R26.2, U10.9 (VM), U11.9 (VM)
unnamed: C53.1, R29.2, R30.1
unnamed: C54.1, R31.2, R32.1
unnamed: C55.1, R35.2, R36.1
unnamed: C56.1, R37.2, R38.1
unnamed: C59.1, R43.2, R44.1
unnamed: C60.1, R45.2, R46.1
unnamed: C63.1, R48.2, R49.1
unnamed: C64.1, R52.2, U12.1 (CH1+), U18.1
unnamed: C65.1, R53.2, U12.3 (CH2+), U18.3
unnamed: C66.1, R54.2, U12.11 (CH3+), U18.6
unnamed: C67.1, R56.2, U12.13 (CH4+), U18.4
unnamed: C68.1, R57.2, R58.1
unnamed: C69.1, R60.2, R61.1
unnamed: C70.1, R63.2, R64.1

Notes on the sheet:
D.N.P.

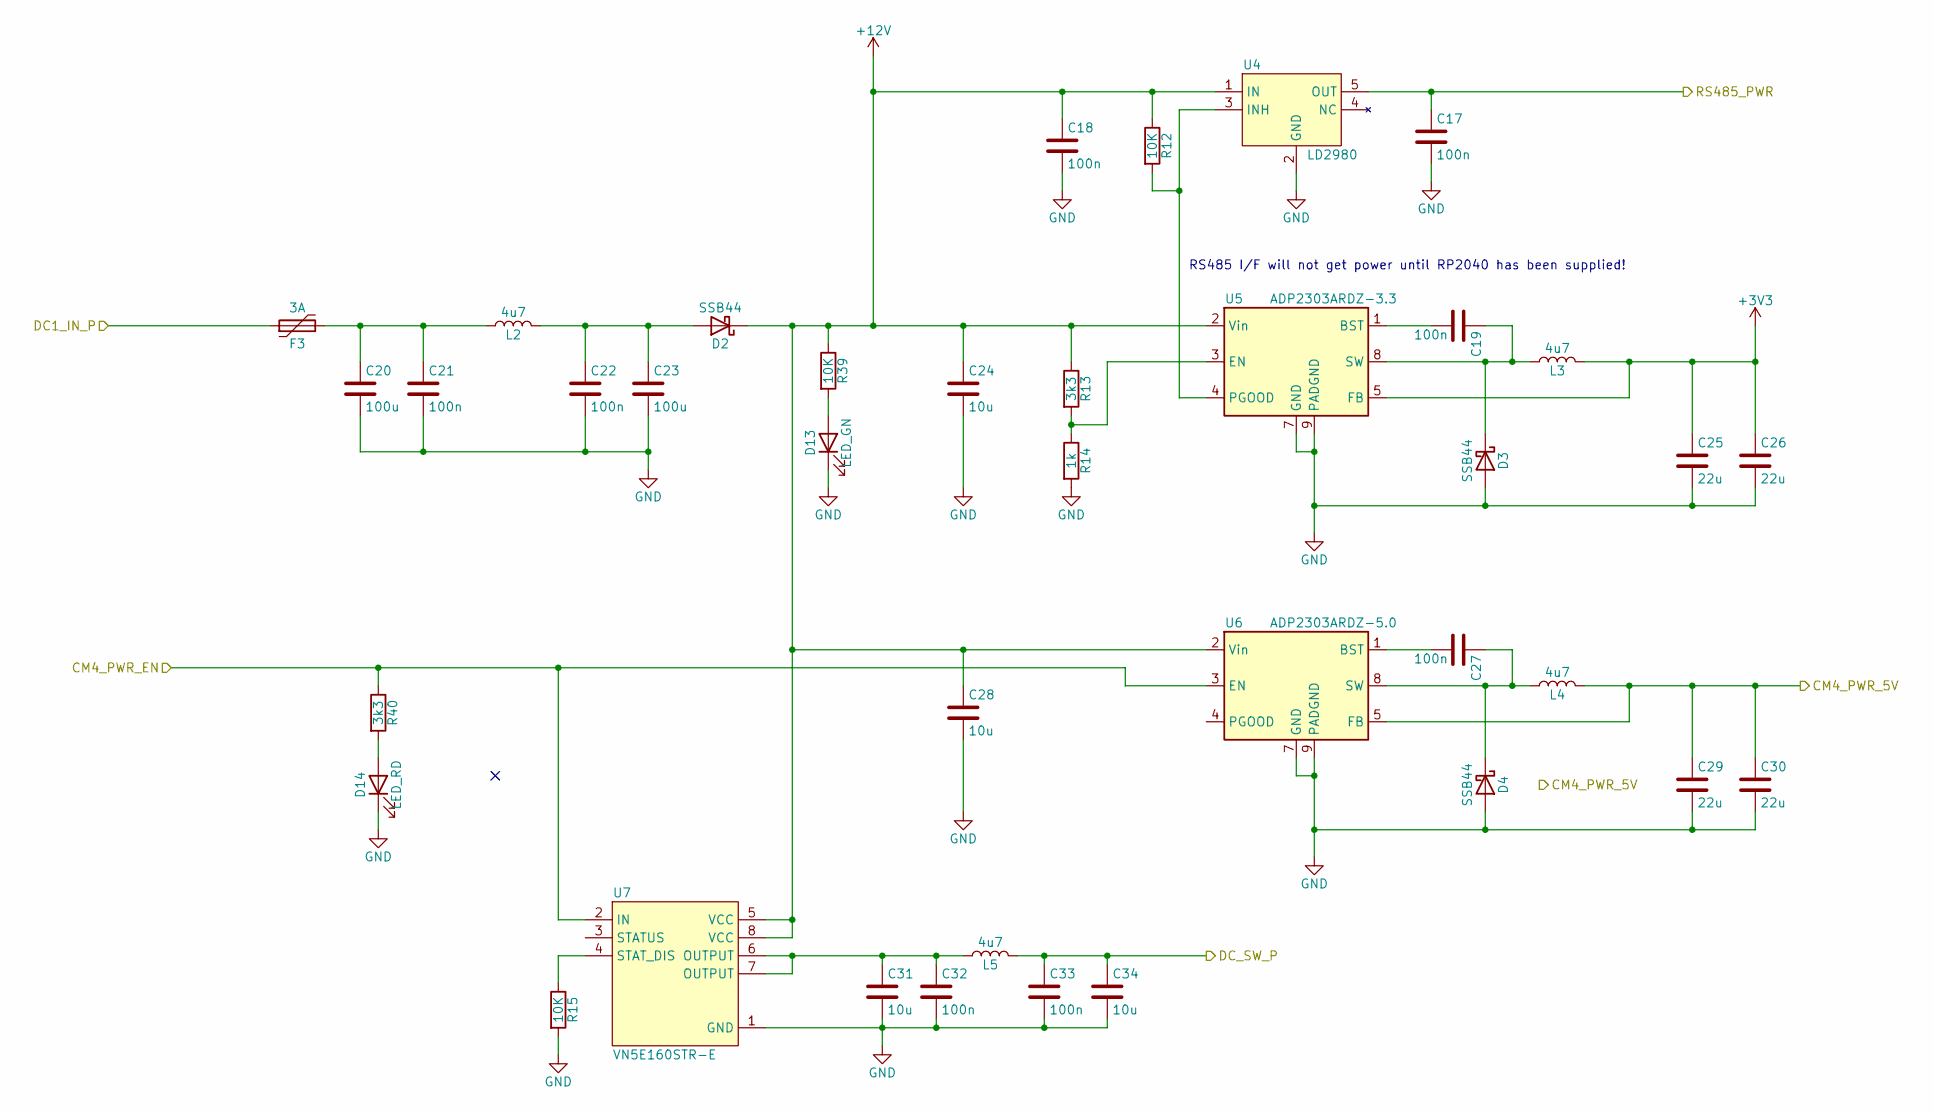
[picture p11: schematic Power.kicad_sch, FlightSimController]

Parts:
C17, C18, C19, C21, C22, C27, C32, C33: 100n; C_0603_1608Metric_Pad1.08x0.95mm_HandSolder; MPN C0603C104K4RACTU
C20, C23: 100u; C_1210_3225Metric; MPN EMK325ABJ107MM-T
C24, C28, C31, C34: 10u; C_0805_2012Metric_Pad1.18x1.45mm_HandSolder; MPN GRM21BR61C106KE15L
C25, C26, C29, C30: 22u; C_0805_2012Metric_Pad1.18x1.45mm_HandSolder; MPN GRM21BR61E226ME44L
D2, D3, D4: SSB44; D_SMB; MPN SSB44-E3/52T
D13: LED_GN; LED_0805_2012Metric_Pad1.15x1.40mm_HandSolder; MPN MP008279
D14: LED_RD; LED_0805_2012Metric_Pad1.15x1.40mm_HandSolder; MPN MP008293
F3: 3A; Fuse_1210_3225Metric_Pad1.42x2.65mm_HandSolder; MPN SF-1206S300-2
L2, L3, L4, L5: 4u7; L_Vishay_IHLP-2020; MPN IHLP2020BZER4R7M01
R12, R15, R39: 10K; R_0603_1608Metric_Pad0.98x0.95mm_HandSolder; MPN RC0603FR-0710KL
R13, R40: 3k3; R_0603_1608Metric_Pad0.98x0.95mm_HandSolder; MPN RC0603FR-073K3L
R14: 1k; R_0603_1608Metric_Pad0.98x0.95mm_HandSolder; MPN RC0603FR-071KP
U4: LD2980; SOT-23-5_HandSoldering; MPN LD2980ABM50TR
U5: ADP2303ARDZ-3.3; SOIC-8-1EP_3.9x4.9mm_P1.27mm_EP2.29x3mm_ThermalVias; MPN ADP2303ARDZ-3.3-R7
U6: ADP2303ARDZ-5.0; SOIC-8-1EP_3.9x4.9mm_P1.27mm_EP2.29x3mm_ThermalVias; MPN ADP2303ARDZ-5.0-R7
U7: VN5E160STR-E; SOIC-8_3.9x4.9mm_P1.27mm; MPN VN5E160STR-E

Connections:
+3V3: C25.1, C26.1, L3.2, U5.5 (FB); also elsewhere on the board
+5V: C29.1, C30.1, L4.2, U6.5 (FB); also elsewhere on the board
+5VP: C17.1, U4.5 (OUT); also elsewhere on the board
+12V: C18.1, C24.1, C28.1, D2.1 (K), R12.1, R13.1, R39.1, U4.1 (IN), U5.2 (Vin), U6.2 (Vin), U7.5 (VCC), U7.8 (VCC)
/CM4_PWR_EN: R40.1, U6.3 (EN), U7.2 (IN); also elsewhere on the board
/Power/DC_SW_P: C33.1, C34.1, L5.2; also elsewhere on the board
GND: C17.2, C18.2, C20.2, C21.2, C22.2, C23.2, C24.2, C25.2, C26.2, C28.2, C29.2, C30.2, C31.2, C32.2, C33.2, C34.2, D3.2 (A), D4.2 (A), D13.1 (K), D14.1 (K), R14.2, R15.2, U4.2 (GND), U5.7 (GND), U5.9 (PADGND), U6.7 (GND), U6.9 (PADGND), U7.1 (GND); also elsewhere on the board
unnamed: C19.1, D3.1 (K), L3.1, U5.8 (SW)
unnamed: C19.2, U5.1 (BST)
unnamed: C20.1, C21.1, F3.2, L2.1
unnamed: C22.1, C23.1, D2.2 (A), L2.2
unnamed: C27.1, D4.1 (K), L4.1, U6.8 (SW)
unnamed: C27.2, U6.1 (BST)
unnamed: C31.1, C32.1, L5.1, U7.6 (OUTPUT), U7.7 (OUTPUT)
unnamed: D13.2 (A), R39.2
unnamed: D14.2 (A), R40.2
unnamed: R12.2, U4.3 (INH), U5.4 (PGOOD)
unnamed: R13.2, R14.1, U5.3 (EN)
unnamed: R15.1, U7.4 (STAT_DIS)
VBUS: F3.1; also elsewhere on the board

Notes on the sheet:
RS485 I/F will not get power until RP2040 has been supplied!

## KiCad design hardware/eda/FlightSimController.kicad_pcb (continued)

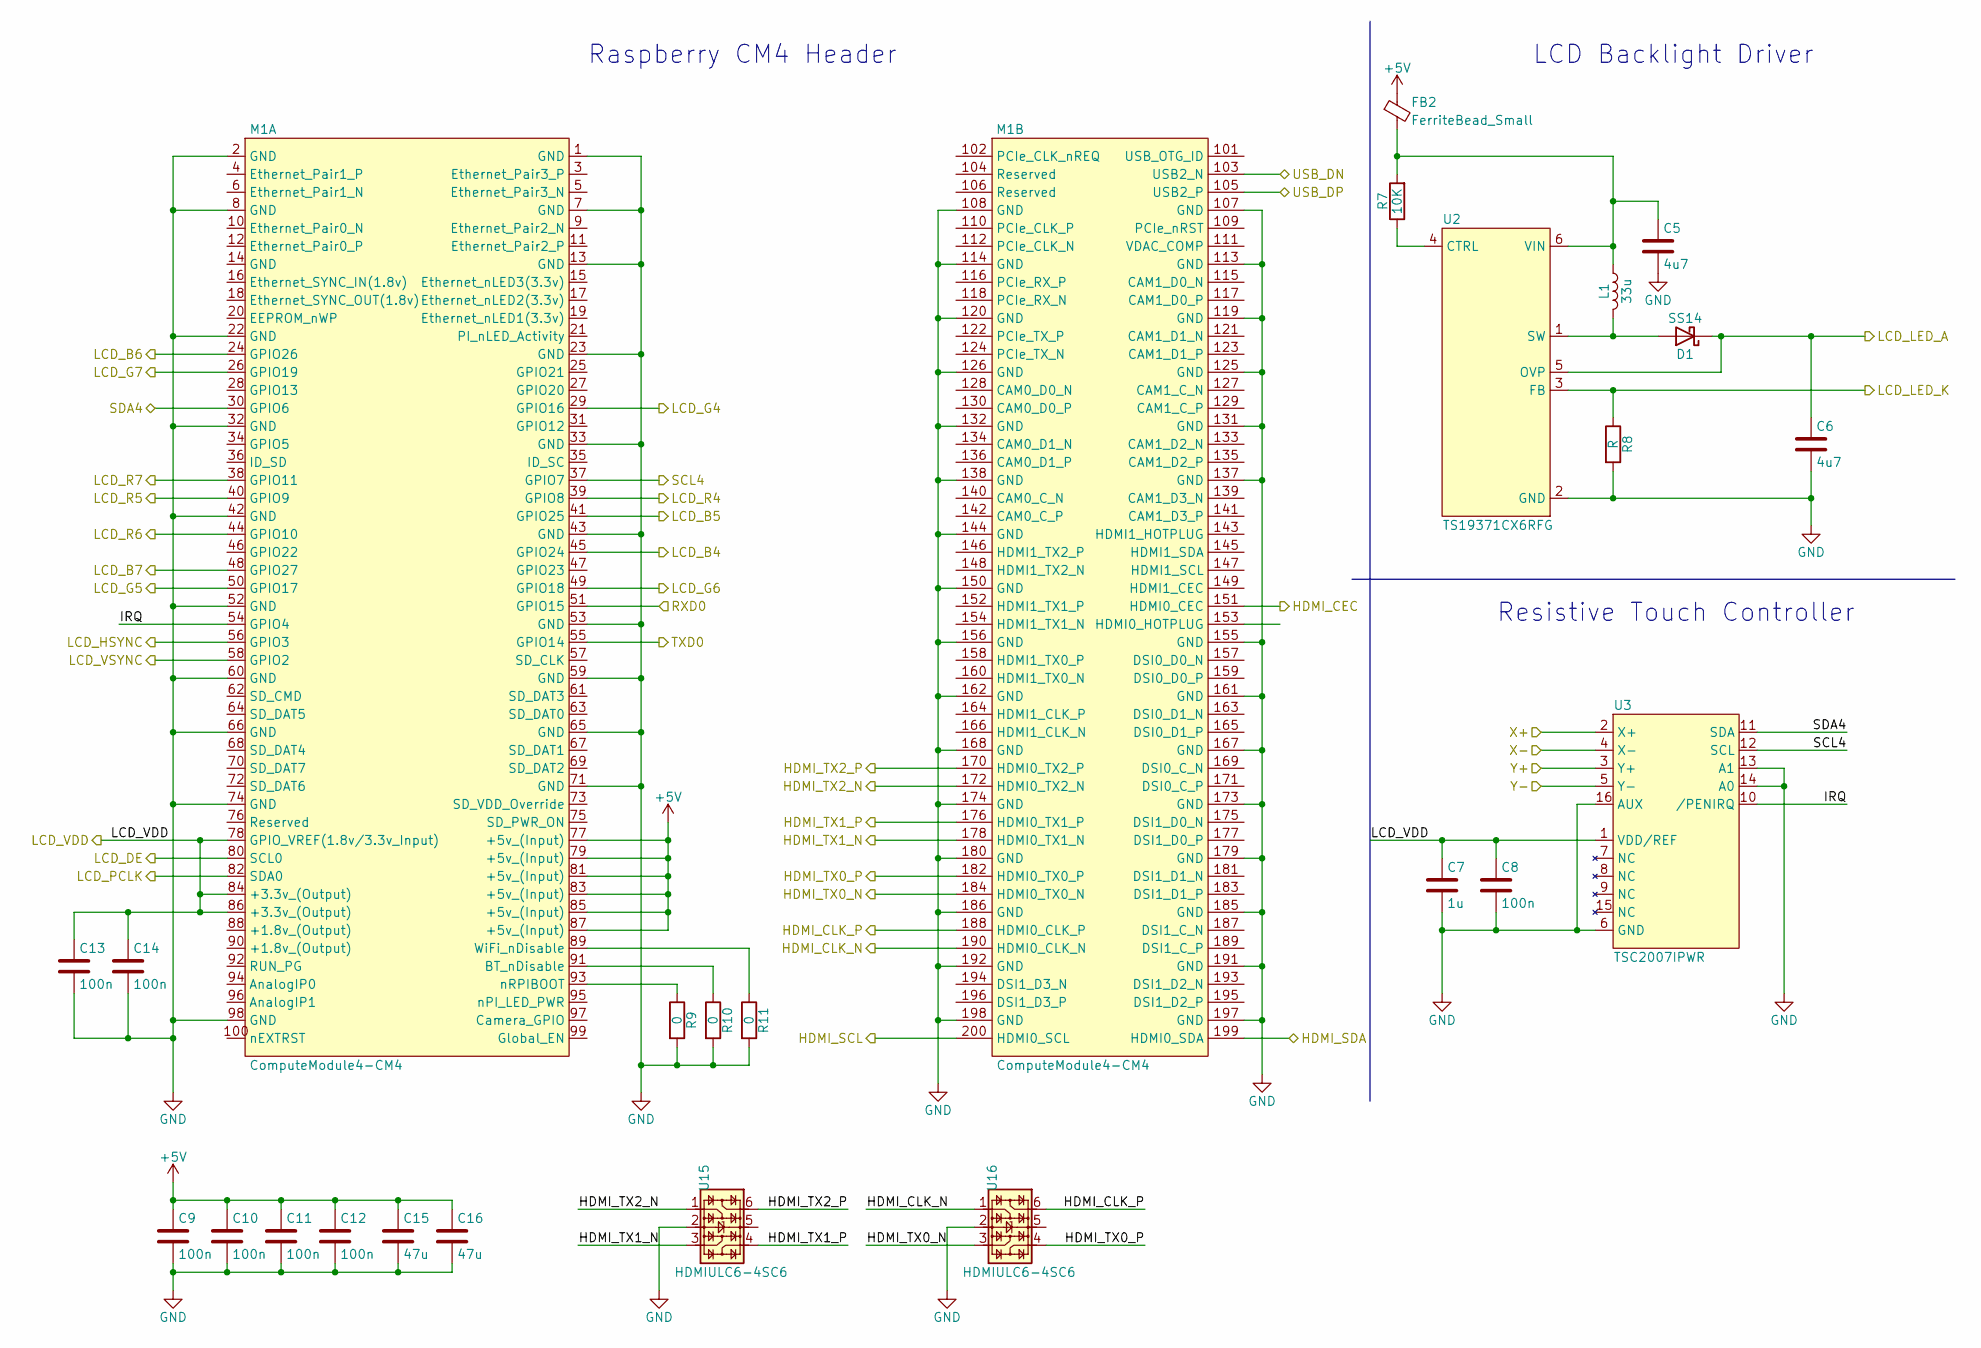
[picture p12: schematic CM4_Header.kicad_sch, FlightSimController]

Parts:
C5, C6: 4u7; C_0805_2012Metric_Pad1.18x1.45mm_HandSolder; MPN GRM21BR61H475KE51L
C7: 1u; C_0603_1608Metric_Pad1.08x0.95mm_HandSolder; MPN CC0603KRX5R6BB105
C8, C9, C10, C11, C12, C13, C14: 100n; C_0603_1608Metric_Pad1.08x0.95mm_HandSolder; MPN C0603C104K4RACTU
C15, C16: 47u; C_0805_2012Metric_Pad1.18x1.45mm_HandSolder; MPN GRM21BR61A476ME15L
D1: SS14; D_SMA_Handsoldering; MPN SS14-E3/61T
FB2: FerriteBead_Small; L_0805_2012Metric; MPN BLM21PG221SN1D
L1: 33u; L_Bourns-SRN4018; MPN SRN4018-330M
M1: ComputeModule4-CM4; Raspberry-Pi-4-Compute-Module; MPN DF40C-100DS-0.4V(51)
R7: 10K; R_0603_1608Metric_Pad0.98x0.95mm_HandSolder; MPN RC0603FR-0710KL
R8: R; R_1206_3216Metric_Pad1.30x1.75mm_HandSolder
R9, R10, R11: 0; R_0603_1608Metric_Pad0.98x0.95mm_HandSolder; MPN RC0603JR-070RL
U2: TS19371CX6RFG; SOT-23-6_Handsoldering; MPN TS19371CX6 RFG
U3: TSC2007IPWR; TSSOP-16_4.4x5mm_P0.65mm; MPN TSC2007IPWR
U15, U16: HDMIULC6-4SC6; SOT-23-6; MPN HDMIULC6-4SC6

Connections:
+5V: C9.1, C10.1, C11.1, C12.1, C15.1, C16.1, FB2.1, M1.77 (+5v_(Input)), M1.79 (+5v_(Input)), M1.81 (+5v_(Input)), M1.83 (+5v_(Input)), M1.85 (+5v_(Input)), M1.87 (+5v_(Input)); also elsewhere on the board
/B4: M1.45 (GPIO24); also elsewhere on the board
/B5: M1.41 (GPIO25); also elsewhere on the board
/B6: M1.24 (GPIO26); also elsewhere on the board
/B7: M1.48 (GPIO27); also elsewhere on the board
/CLK: M1.82 (SDA0); also elsewhere on the board
/CM4 Header/HDMI_CEC: M1.151 (HDMI0_CEC); also elsewhere on the board
/CM4 Header/HDMI_CLK_N: M1.190 (HDMI0_CLK_N), U16.1; also elsewhere on the board
/CM4 Header/HDMI_CLK_P: M1.188 (HDMI0_CLK_P), U16.6; also elsewhere on the board
/CM4 Header/HDMI_SCL: M1.200 (HDMI0_SCL); also elsewhere on the board
/CM4 Header/HDMI_SDA: M1.199 (HDMI0_SDA); also elsewhere on the board
/CM4 Header/HDMI_TX0_N: M1.184 (HDMI0_TX0_N), U16.3; also elsewhere on the board
/CM4 Header/HDMI_TX0_P: M1.182 (HDMI0_TX0_P), U16.4; also elsewhere on the board
/CM4 Header/HDMI_TX1_N: M1.178 (HDMI0_TX1_N), U15.3; also elsewhere on the board
/CM4 Header/HDMI_TX1_P: M1.176 (HDMI0_TX1_P), U15.4; also elsewhere on the board
/CM4 Header/HDMI_TX2_N: M1.172 (HDMI0_TX2_N), U15.1; also elsewhere on the board
/CM4 Header/HDMI_TX2_P: M1.170 (HDMI0_TX2_P), U15.6; also elsewhere on the board
/CM4 Header/IRQ: M1.54 (GPIO4), U3.10 (/PENIRQ)
/CM4 Header/RXD0: M1.51 (GPIO15); also elsewhere on the board
/CM4 Header/SCL4: M1.37 (GPIO7), U3.12 (SCL); also elsewhere on the board
/CM4 Header/SDA4: M1.30 (GPIO6), U3.11 (SDA); also elsewhere on the board
/CM4 Header/TXD0: M1.55 (GPIO14); also elsewhere on the board
/DE: M1.80 (SCL0); also elsewhere on the board
/G4: M1.29 (GPIO16); also elsewhere on the board
/G5: M1.50 (GPIO17); also elsewhere on the board
/G6: M1.49 (GPIO18); also elsewhere on the board
/G7: M1.26 (GPIO19); also elsewhere on the board
/HSYNC: M1.56 (GPIO3); also elsewhere on the board
/LCD_VDD: C7.1, C8.1, C13.1, C14.1, M1.78 (GPIO_VREF(1.8v/3.3v_Input)), M1.84 (+3.3v_(Output)), M1.86 (+3.3v_(Output)), U3.1 (VDD/REF); also elsewhere on the board
/LED_A: R8.1, U2.3 (FB); also elsewhere on the board
/LED_K: C6.1, D1.1 (K), U2.5 (OVP); also elsewhere on the board
/R4: M1.39 (GPIO8); also elsewhere on the board
/R5: M1.40 (GPIO9); also elsewhere on the board
/R6: M1.44 (GPIO10); also elsewhere on the board
/R7: M1.38 (GPIO11); also elsewhere on the board
/USB_D_N: M1.103 (USB2_N); also elsewhere on the board
/USB_D_P: M1.105 (USB2_P); also elsewhere on the board
/VSYNC: M1.58 (GPIO2); also elsewhere on the board
/X+: U3.2 (X+); also elsewhere on the board
/X-: U3.4 (X-); also elsewhere on the board
/Y+: U3.3 (Y+); also elsewhere on the board
/Y-: U3.5 (Y-); also elsewhere on the board
GND: C5.2, C6.2, C7.2, C8.2, C9.2, C10.2, C11.2, C12.2, C13.2, C14.2, C15.2, C16.2, M1.1 (GND), M1.2 (GND), M1.7 (GND), M1.8 (GND), M1.13 (GND), M1.22 (GND), M1.23 (GND), M1.32 (GND), M1.33 (GND), M1.42 (GND), M1.43 (GND), M1.52 (GND), M1.53 (GND), M1.59 (GND), M1.60 (GND), M1.65 (GND), M1.66 (GND), M1.71 (GND), M1.74 (GND), M1.98 (GND), M1.107 (GND), M1.108 (GND), M1.113 (GND), M1.114 (GND), M1.119 (GND), M1.120 (GND), M1.125 (GND), M1.126 (GND), M1.131 (GND), M1.132 (GND), M1.137 (GND), M1.138 (GND), M1.144 (GND), M1.150 (GND), M1.155 (GND), M1.156 (GND), M1.161 (GND), M1.162 (GND), M1.167 (GND), M1.168 (GND), M1.173 (GND), M1.174 (GND), M1.179 (GND), M1.180 (GND), M1.185 (GND), M1.186 (GND), M1.191 (GND), M1.192 (GND), M1.197 (GND), M1.198 (GND), R8.2, R9.2, R10.2, R11.2, U2.2 (GND), U3.6 (GND), U3.13 (A1), U3.14 (A0), U3.16 (AUX), U15.2, U16.2; also elsewhere on the board
unnamed: C5.1, FB2.2, L1.1, R7.2, U2.6 (VIN)
unnamed: D1.2 (A), L1.2, U2.1 (SW)
unnamed: M1.89 (WiFi_nDisable), R11.1
unnamed: M1.91 (BT_nDisable), R10.1
unnamed: M1.93 (nRPIBOOT), R9.1
unnamed: R7.1, U2.4 (CTRL)

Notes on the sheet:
LCD Backlight Driver
Raspberry CM4 Header
Resistive Touch Controller

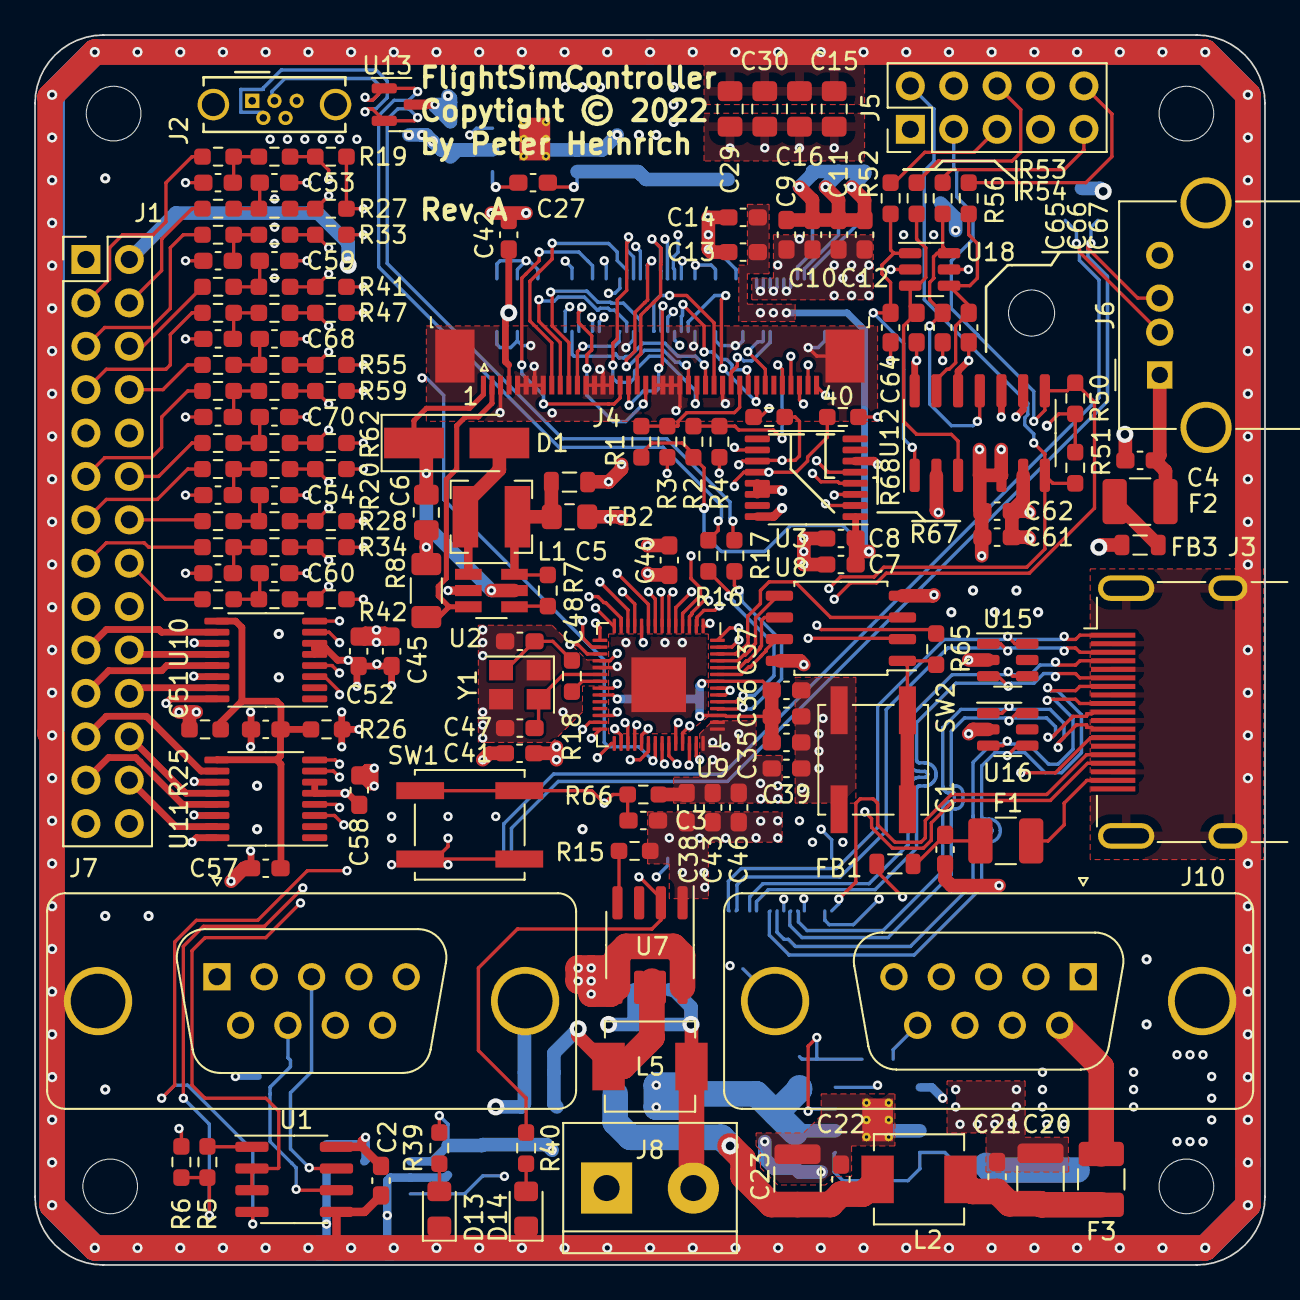
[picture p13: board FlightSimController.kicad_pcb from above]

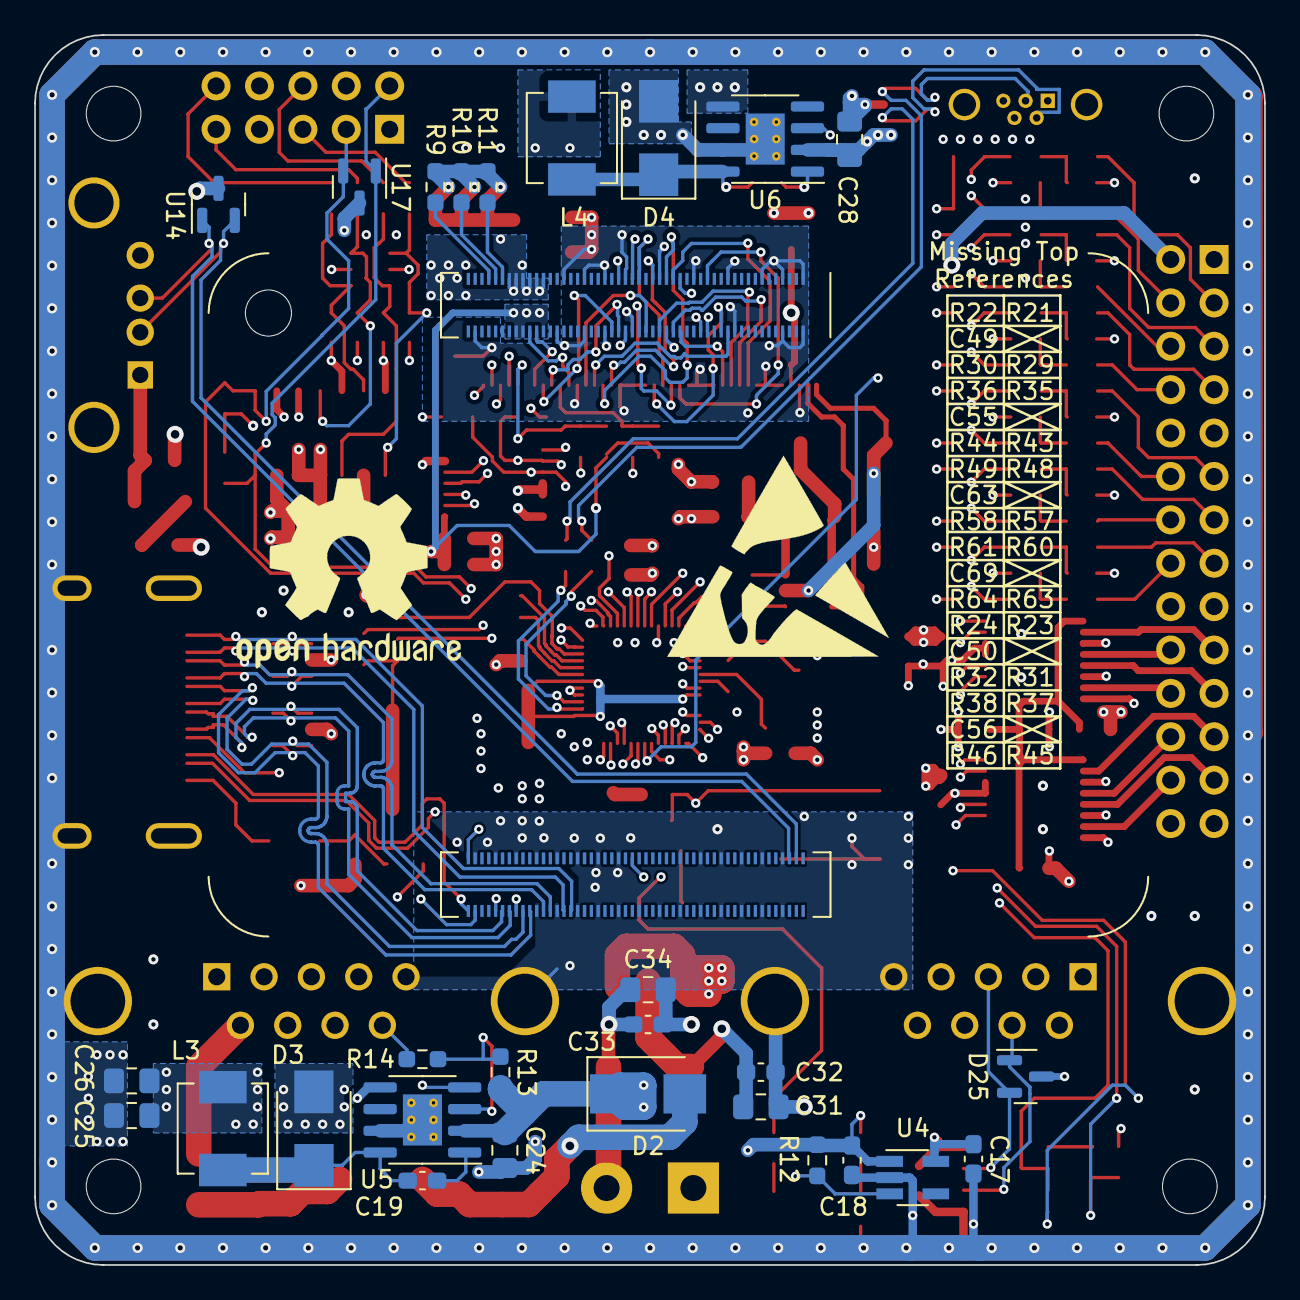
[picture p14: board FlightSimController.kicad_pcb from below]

Board: 6 copper layers, 72.0 x 72.0 mm, 190 parts (29 on the bottom side), 158 nets.

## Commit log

2022-12-06 Silkscreen Adjustments
    [FlightSimController.kicad_pcb]
2022-12-06 Updating Backlight Controller Sense Resistor
    [CM4_Header.kicad_sch, FlightSimController.kicad_sch]
2022-12-06 Adding Procurement Ordering Information
    [FlightSimController.csv, GPIO.kicad_sch, OrderFarnell_FullBoard.csv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]
2022-12-06 Updating Schematic

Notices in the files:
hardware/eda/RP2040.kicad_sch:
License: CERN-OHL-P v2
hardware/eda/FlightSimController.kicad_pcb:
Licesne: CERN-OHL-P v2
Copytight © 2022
